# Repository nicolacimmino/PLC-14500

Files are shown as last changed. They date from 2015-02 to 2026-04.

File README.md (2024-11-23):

**NEW!** You can now buy this as a ready to assemble kit on [tindie.com](https://www.tindie.com/products/28867/).

# Introduction

The PLC14500 Nano is a retro-style trainer board intended for the user to familiarize with the Motorola MC14500 1-bit
ICU (Industrial Control Unit), PLCs and Ladder Logic. The board has abundant LEDs that show the status of 
the system buses and registers. This, combined with the possibility to run the software step by step,
gives the user a great deal of insight into how their programs are executing. The slow clock mode 
makes instead for a mesmerizing light show that won't fail to impress when the board is parked on a desk,
waiting for the next coding adventure.

Main features:

* 256 Bytes of program RAM (can be replaced with an EEPROM)
* 7 Inputs each with toggle and momentary switch capability
* 7 Outputs (LEDs)
* 1 Timer mapped to the I/O bus (0.5 to 11s, adjustable via a trimmer)
* 7 bits scratchpad RAM
* 3 clock modes (fast, slow, manual step)

True to its retro style PLC14500 Nano sports exclusively through-hole components and chips in DIP packages.
You might notice an intruder in the Bill of Materials, an Arduino Nano! It's there purely to act as a
bootloader, with a convenient USB interface that surely is easy to connect to modern PCs. However,
to not spoil the illusion, the Arduino is mounted on the bottom side of the PCB, so it won't be visible when 
using the board.

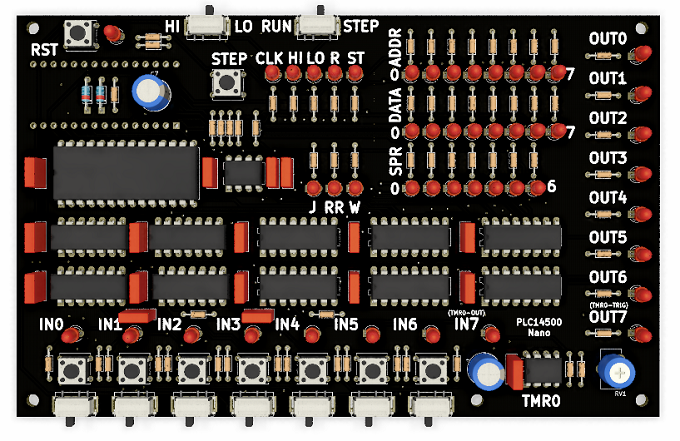
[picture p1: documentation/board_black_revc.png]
Board


This project is Open Source Hardware [Certified](https://certification.oshwa.org/pl000011.html)

oshw_PL000011

# Toolchain

You can find all the tools to assemble and transfer programs ready built for Windows in the [releases](https://github.com/nicolacimmino/PLC-14500/releases) section.

In addition to the tools in this repo, Hein Pragt was so kind to build a workbench that you can use to simulate your programs while waiting to build the board. See an in-depth explanation of the MC14500 and of the tool on his [website](https://www.heinpragt.nl/?p=2749).

# Assembling the board

To keep the assembled board visually free from clutter, and to give more prominence to the labels
relevant in regular use, it was chosen to hide the component reference numbers on the silkscreen.
Where possible these are on the silkscreen under the component itself but, where not possible, 
these have been omitted completely. To help with the assembly please refer to the assembly view 
available in the `board` folder.

**NOTE** Make sure you refer to the right revision of the board matching the one you have. The board
revision can be found on the bottom side silk screen (eg `PLC14500 Nano REV.A`)

As usual start from the lower profile components (such as resistors and ICs), and work towards taller
profile ones, to finish with large caps and the trimmer. 

**NOTE** The Arduino Nano is to be assembled on the bottom side of the board, opposite the components,
as indicated in the silk screen. Also, make sure D40, D51, R54, C7 are soldered BEFORE you solder the 
Arduino as their PINs are under the Arduino board.

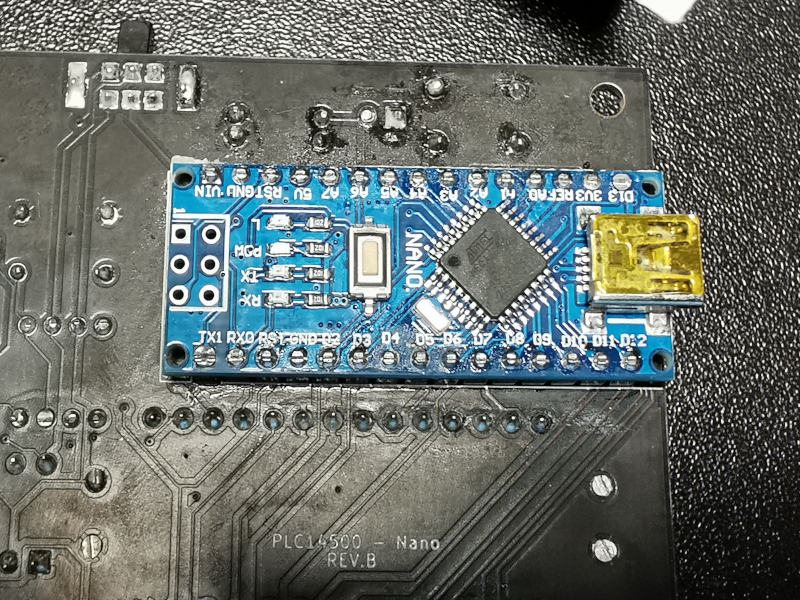
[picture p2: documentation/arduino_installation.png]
Arduino Installation


# Getting started

Download the latest toolchain (Windows only at the moment) from this Git repo [releases folder](https://github.com/nicolacimmino/PLC-14500/releases) and unzip it.

Before starting writing your programs and testing them on the board, you will need to flash the bootloader
into the Arduino. This can be easily done with the Arduino IDE. Load the sketch `bootloader.ino` from  the
release zip and make sure the board selected in the Arduino IDE is "Arduino Nano". Connect the board to your PC 
with a USB cable and select, in the Arduino IDE, the new serial port that will be assigned to the board. 
Upload the sketch and you are ready to go. Take note of the serial port name as you will need it to flash the
programs later.

Unless there will be an update to the bootloader you won't need to repeat this step in the future.

# Assembling a program

You can write your programs in a text editor of your choice, as long as you save them with a `.asm`
extension. This is a first example program to make sure your board is correctly assembled and functioning.
You can find this code also in the release zip file under `examples\smoketest.asm`.

````
.board=PLC14500-Nano

; *************************************************
; Prepare:
; All inputs off except IN6 (master switch).
; *************************************************

IEN IN6   ; IN6 acts as master switch
OEN IN6   ; to enable/disable all I/O

; *************************************************
; Test: Input and outputs are working correctly

LD  IN0   ; Load IN0,
AND IN1   ; logical AND it with IN1
STO OUT0  ; and show the result in OUT0.

; Expect: OUT0 is on only when both IN0 and IN1 are on.
; *************************************************

; *************************************************
; Test: TMR0 is working correctly

LD  IN2   ; Load IN2
STO OUT7  ; use it to trigger TMR0.

; Expect: Clicking IN2 on turns on IN7 (TMR0 output)
;   and, after few seconds, IN7 returns off.
; *************************************************

; *************************************************
; Test: Scratchpad RAM is working correctly.

LD  IN3    ; Copy IN3 to SPR0
STO SPR0

LD  SPR0   ; Copy SPR0 to SPR1
STO SPR1

; Expect: Clicking IN3 turns on SPR0 and SPR1
; *************************************************

JMP 0     ; Repeat.
````

Save it to a `test.asm` file and assemble it into a binary with the assembler found in the release zip file:

````
.\asm14500.exe .\test.asm
````

This will produce a `test.bin` file, which should be 256 bytes in size.

# Transferring a program to the board

To transfer the assembled `.bin` file to the board program RAM, make sure the USB cable is plugged in and take note of which serial port 
your board got mapped to in the Arduino IDE. You can then upload the flash command found in the release zip file:

````
.\flash14500 test.bin COM3
````

Replacing `COM3` with the correct port number for your board. Also remember to press the RST button on the board once the upload is done, and verify
that the top switches are in the "HI" and "RUN" positions respectively so the program runs.

# Testing

If you uploaded the above example program you can verify the board correct functioning by following the steps in the sourcecode that will guide you
through the needed settings and actions and expected outcomes.

**Help!!** some LEDs like `J`, `RR` or `W` randomly change intensity when I click other buttons. Do I have have a short somewhere? Did I break something? **no**,
don't worry. This is absolutely normal when the board is running on the normal clock (`HI` and `RUN`), this is because those LEDs are actually flashing on and off
as the MC14500 executes instructions. Because of the high clock speed you don't see the actual flickering but the resulting intensity depends on how often your program
causes them to be on (and for this reason, depending on the program, this is dependent on status of the inputs). This is also true for the `ADDR`, `DATA` and `SPR` LEDs when running with full clock. To convience yourself about this, and for a cool blinking effect, turn the clock to `LO` and watch, just don't expect outputs to react to your clicks promptly!

# What's next

Read more about the assembler and the `.asm` file syntax in the assembler folder [README.md](assembler/README.md).

To get started with programming your board and for some ideas of new programs you can try to make yourself, read the [Programmers Guide](assembler/programmers_guide.md).

If you find any issues, or want to contribute code/comments please feel free to use the "Issues" tool here on GitHub.

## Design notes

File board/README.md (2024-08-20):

## REV_A -> REV_B

- Moved LED labelled HI to the left of LO (to match switch direction)

- Added 47K in series to U2 Pin3 OUT (to remove gosthing of outputs on inputs LEDs due to MC14500 W line timing)

- Passed OUT7 through a NOT before triggering TMR0, left LED direct to OUT7 (NE555 triggers on low which makes it hakward without negation as the monostable triggers always once on reset)

- Swapped RV1 Pin3 and Pin1 (so clockwise rotation increases time)

*NOTE* REV.A was never on sale, it was a pre-production proto. If you have got a REV.A you either got a
knockoff by someone who got the gerbers in the early days or somehow you got hold of a display unit
from a museum.

## REV_B -> REV_C

- Replaced SPR7 with RR so that RR can be read at IO $7
- Replaced C4 with a 10uF and RV1 with 1M. Similar timing but more consistent when triggered by short pulses.

  (Thanks to [wrh3c](https://github.com/wrh3c) for the suggestion).

If you have a REV.B and you are interested in experimenting with the ION/OEN driven if/else structures
described in the Motorola's own MC14500 Handbook, you will need a tiny modification to the board. This
will replace SPR7 input signal with RR so that you can control IEN/OEN registers fully.

- Cut pin 1 of U13 (isolates the Q7 output of the CD4099, leaving what used to be SPR7 floating )
- Connect the **pad** of pin 1 of U13 to pin 15 of U10 (thus connecting the MC14500 RR to what used to be SPR7 input)
- If having the SPR7 LED confuses you, cut LED D50

## REV_C -> REV_D

- Corrected clock source to feed into X2 and used X1 to drive the counter. There are no functional changes.

- Added LEDs also for RTN, FLAG0, FLAGF. Even though these signals are not relevant for this design
	many asked to have them visible for educational purpuses.

- Rearranged ADDR, DATA, SPR LEDs to have lsb on the right.

- Rearranged OUT LEDs in a more compact layout like the others.

- Added an expansion connector to use external inputs/outputs.

- Swapped around the wiring of input switches so that right is ON left is OFF.

- Swapped around the wiring of the clock switches so that HI and RUN are on the right.

## REV_D Artifacts

Silk
Silk

Assembly
Assembly

TopCopper
Top

BottomCopper
Bottom

## REV_C Artifacts

Silk
Silk

Assembly
Assembly

TopCopper
Top

BottomCopper
Bottom

## REV_B Artifacts

Silk
Silk

Assembly
Assembly

TopCopper
Top

BottomCopper
Bottom

## REV_A Artifacts

Silk
Silk

Assembly
Assembly

TopCopper
Top

BottomCopper
Bottom

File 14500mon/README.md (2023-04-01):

# 14500MON (PLC14500 Assembler and Monitor)

Your PLC14500 comes preloaded with the 14500MON. This interactive assembler/monitor is an homage, both in the name and
in the syntax, to the classic C64 monitor 64Mon and other similar implementations.

**Note:** while 14500MON is compatible with ALL revisions of the board, early REV.B and a batch of REV.C boards were shipped
without it (the regular bootloader only was provided). You can just use an Arduino IDE to load the sketch on your PLC14500 (Choose Arduino Nano under AVR Boards
and make sure you choose the "Old Bootloader" variant).

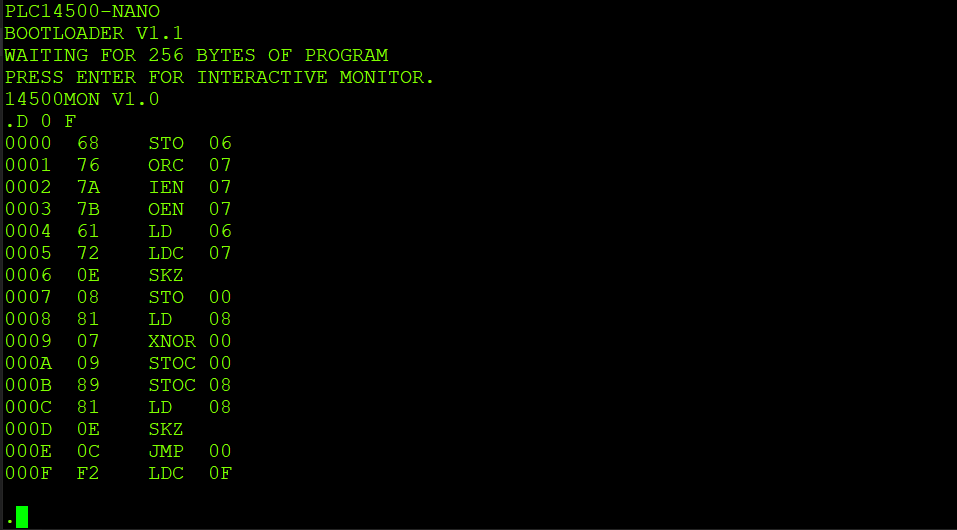
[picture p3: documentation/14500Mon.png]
14500mon


To verify if you have the 14500MON already installed, open a terminal program (e.g. PuTTY) and connect to the PLC14500
serial port (9600 BAUD, no parity, 8bits, 1 stop bit). After a few seconds you should receive the prompt:

````
PLC14500-NANO
BOOTLOADER V1.1
WAITING FOR 256BYTES OF PROGRAM
PRESS ENTER FOR INTERACTIVE MONITOR.
````

Press enter and you will be in the monitor. The monitor will exit automatically after 30s of inactivity, or you can exit
by giving the “X” command.

**Note:** while the monitor is active, even if you disconnect the serial port, the bootloader won’t be running and you
will
not be able to flash new programs until it exits.

**Warning:** Depending on the settings used on your terminal app, the first usage of “flash14500.cmd” after exiting the
monitor might not transfer the program correctly. This is because “flash14500.cmd” might end up toggling the serial port
control lines causing the Arduino to reset. This introduces a delay that will make it miss the payload. Any further
flashing after the first will work as expected.

# Commands

The following commands are available in 14500MON and can be listed at any moment by using the “H” command. Just type “H”
at the prompt and press enter.

````
.H
A [START]       ASSEMBLE
D [START] [END] DISASSEMBLE
L [BLOCK]       LOAD
M [START] [END] DUMP MEMORY
S [BLOCK]       SAVE
T TRACE
W [START]       WRITE MEMORY
X EXIT
````

## Assemble

The built-in assembler is a great way to try small programs and see them immediately running on the board. It also gives
you a more down to the machine view of how assembly language is converted to bytecode.

To assemble interactively simply use the “A” command followed by the start address and press enter:

````
.A 0
````

The assembler will reply with something like:

````
.A 0
0000 68 STO 06 .
````

The first four digits are the address and the following number is the memory content at that location. This is followed
by a disassembly of the instruction at that address and the “.” prompt. We can now type a new instruction to be
assembled at this location, for instance “LD 6” and press enter. The instruction will be assembled, written to memory,
and the assembler will move to the next location.

````
.A 0
0000 68 STO 06 .LD 6
0001 76 ORC 07 .
````

We can continue in this way to assemble our program. If we leave a line empty and just press enter the assembler will
move to the next memory location and leave the current one untouched. This is useful for instance to revise the current
program and fix only some instructions if a bug is found.

````
.A 0
0000 68 STO 06 .LD 6
0001 76 ORC 07 .LD 7
0002 7A IEN 07 .
````

Once we are done we can exit the assembler with the “X” command.

````
.A 0
0000 68 STO 06 .LD 6
0001 76 ORC 07 .LD 7
0002 7A IEN 07 .
0003 7B OEN 07 .X
````

**Note:** while you are in the "assemble" command, the board stops executing code. Normal execution will resume once you
exit the assembler. This prevents inconsistencies that could be caused by non-complete code being executed.

**Note:** the program you are assembling is stored in the PLC14500-Nano onboard RAM but is not persisted in the
bootloader storage. If you power cycle the board, the old program will be re-loaded. To persist your changes for the
next boot see the “SAVE” command.

Remember to always press “RST” after modifying the code to ensure your I/O latches start from a clean state.

## Load

The “LOAD” command, invoked with “L”, will cause a program currently in the bootloader EEPROM to be loaded into the
PLC14500-Nano onboard RAM for immediate execution.

The bootloader has four separate blocks of storage that can store one program each. Block 0 is the one loaded by the
bootloader when the board is powered up. The programs in the other three blocks can be loaded only with the “LOAD”
command.

The “L” command takes one argument, that is the block number to be loaded. Block numbers above 3 will cause an error.

````
.L 1
LOADING................
````

**Note:** Remember to always press “RST” after modifying the code to ensure your I/O latches start from a clean state.

## Save

The “SAVE” command, invoked with “S”, will cause the program currently in the PLC14500-Nano onboard RAM to be persisted
in a bootloader EEPROM block for later retrieval.

The bootloader has four separate blocks of storage that can store one program each. Block 0 is the one loaded by the
bootloader when the board is powered up. The programs in the other three blocks can be loaded only with the “LOAD”
command.

The “S” command takes one argument, that is the block number to be loaded. Block numbers above 3 will cause an error.

````
.S 1
SAVING................
````

**Note:** only block 0 can be written from the USB through the bootloader. The other three blocks are meant to be used
by the interactive monitor with the “SAVE” and “LOAD” commands. You can save on block 0, this program will be
automatically loaded next time you boot the board. However, keep in mind if you transfer a program from the USB port
this block will be overridden.

## Disassemble

The disassemble command can be invoked with “D” followed by a start and end address (in hexadecimal). The start address
is optional and, if omitted, 0 will be assumed. The end address is also optional and, if omitted, the program will be
disassembled till the end of program memory.

````
.D 0 5
0000 68 STO 06
0001 76 ORC 07
0002 7A IEN 07
0003 7B OEN 07
0004 61 LD 06
0005 72 LDC 07
````

Each line of the disassembly shows the address, the numeric content of the memory location, and the mnemonic and operand
this translates to. Because the MC14500 has 16 instructions and 4-bit wide instruction bus there are no illegal opcodes,
so any memory content will always produce a valid disassembly.

## Dump Memory

The dump memory command can be invoked with “M” followed by the start and end address (in hexadecimal). The start
address is optional and, if omitted, 0 will be assumed. The end address is also optional and, if omitted, the memory
will be dumped till the end of program memory.

````
.M 0 1F
0000 68.76.7A.7B.61.72.0E.08
0008 81.07.09.89.81.0E.0C.F2
0010 7B.F8.F9.51.68.41.58.31
0018 48.21.38.11.28.01.18.61
````

Each line shows the address of the first byte, followed by the values of the memory content for the following eight
memory locations.

**Note:** if the selected start doesn’t align to an eight byte boundary, values will still be printed in blocks aligned
to the boundary, just with the unwanted values missing. This can be seen in the example below:

````
.M 3 1B
0000 7B.61.72.0E.08
0008 81.07.09.89.81.0E.0C.F2
0010 7B.F8.F9.51.68.41.58.31
0018 48.21.38.11.
````

## Write Memory

The "write memory" command can be invoked with “W” followed by the start address. The start address is optional and, if
omitted, 0 will be assumed. The monitor will show the first address, followed by the current content of that memory
location . A new value can be entered and will be stored in memory when enter is pressed. It’s possible to leave the
line empty and just press enter to skip that memory location without changing its contents.

````
.W A3
00A3 0F .12
00A4 0F .F0
00A5 0F .
00A6 0F .
00A7 0F .X
.
````

**Note:** the program you are entering in this way is stored in the PLC14500-Nano onboard RAM but is not persisted in
the bootloader storage. If you power cycle the board, the old program will be re-loaded. To persist your changes for the
next boot see the “SAVE” command.

Remember to always press “RST” after editing the program to ensure your I/O latches start from a clean state.

## Trace Program Execution

Thanks to [wrh3c](https://github.com/wrh3c) from whom I got the inspiration to add the Trace mode.

The “Trace Program” mode can be entered using the “T” command. In this mode the monitor will keep outputting the current
instruction being executed.

````
.T
ADDR DATA OP ARG
001B 18 STO 01
001C 61 LD 06
001D 08 STO 00
001E 01 LD 00
001F 88 STO 08
.
````

The output shows the current memory address at which the Program Counter is at, the data in memory at that location and
a disassembly of the instruction. The trace mode will continue until you press a key.

This command is extremely useful when combined with the single step clock as it allows to see the exact instruction
being executed in a more direct way than analysing the LEDs on the board.

**Note:** due to the nature of the PLC14500-Nano bus control, the monitor is not able to keep up with the program being
run at full clock speed (and neither would your eyes). If the trace mode is running with the clock running at full speed
the following error will be displayed:

````
.T
ADDR DATA OP ARG
0004 61 LD 06
0006 0E SKZ
TOO FAST, CAN’T KEEP UP. TURN CLOCK TO LO OR STEP.
````

Changing the clock to LO or STEP will resume the trace at the next clock cycle.

**Note:** there’s no timeout for the trace command. If you leave your board in trace mode the bootloader will not be
able to
receive new programs. If this happens, reconnect to the serial port, press any key and exit the monitor with “X”.
Alternatively you can just unplug and replug the USB cable or reset the Arduino (the RST button on the board itself will
NOT affect the bootloader, just the board PC and I/O latches).

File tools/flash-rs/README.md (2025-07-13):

# flash-rs (PLC14500 Program Flasher and Interactive Monitor Terminal Emulator)
flash-rs will upload a program to the PLC14500 and then provide access to the interactive monitor.

## Use
First install a Rust compiler.  You can find one [here](https://www.rust-lang.org/tools/install).  Then, build the flash-rs for your machine by running the following command anywhere within the flash-rs project  
`cargo build`  

An executable will now be present in the target directory, and you can run the executable directly or use  
`cargo run`

## Syntax
`./flash-rs <program filepath> <serial port interface>`  
Example:  
`./flash-rs example.bin /dev/ttyUSB0`

There's a number of different ways to produce a program.  See the [Getting Started of this repository](https://github.com/nicolacimmino/PLC-14500/blob/master/README.md) as well as the [Assembler Repository](https://github.com/nicolacimmino/plc-14500-assembler).

## Known issues
* When using the trace feature, you cannot exit the trace by pressing X.  You can get out by setting the speed switch to HI to cause an error or by pressing the reset switch on the Arduino.

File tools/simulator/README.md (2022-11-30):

# Simulator

Simulator for PLC14500-Nano board.

This is Work Heavily in Progress. 

A flutter application to toy around with the board while you wait to receive the kit. The app roughly works and basic programs seem to run. Nothing is tested properly though and layout is still a mess.

This will not be part of the first release. However, I plan to polish it later and make a static website out of it for people to play around.

simulator

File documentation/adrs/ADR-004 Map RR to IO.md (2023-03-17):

Status: #Accepted

## Context

The original design of the board doesn't map the MC14500 RR output to the I/O bus. This means that
the OEN instruction cannot be used to its full power to create conditional IF/ELSE blocks.

## Decisions

Reduce SPR size to 7 bits and use SPR7 as an input wired directly to the MC14500 RR pin.

## Consequences

Board needs to be adapted and bumped to REV.C
Assembler needs to be updated to define a RR label.
SPR7 won't be anymore usable for write and reading it will always return RR.

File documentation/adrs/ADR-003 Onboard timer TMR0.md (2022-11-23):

Status: #Accepted

## Context

Given the nature of the board (a trainer board), the onboard TMR0 range can be limited, hence simplifying the design.

## Decisions

It's been decided to have a range for TMR0 from 1s to 6s, while this would be way too short for most practical applications, it suites very well the purpose in the context of test apps for which it's not desirable to have long times to wait for an event to happen. The 1s time constant also allows for blinking of an output if desired.

## Consequences

TMR0 can be implemented with a single 555. A 10K trimmer, with a fixed 2K2 resistor will give the desired range with a 470uF cap.

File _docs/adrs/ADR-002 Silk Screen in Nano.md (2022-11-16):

Status: #Accepted

## Context

Given the limited board space and the amount of components the silk screen for the top layer is rather cluettered. This doesnt sit well with the nature of the board which is in itself a display. The user needs to clearly identify the LEDs functions (eg address bus, inputs, outputs, SPR etc.).

## Decisions

It's been decided to keep the silk screen content unclattered and give prominence to the text relevant to the user during normal usage (as opposed to the assembly phase). This can be achieved by moving all components references under the component itself where possible, so it won't be visible after assembly. Where not possible to fit it under the component it will be hidden completely.

## Consequences

To aid the user in the kit assembly a layout of the components will need to be provided in printed form. This is available from KiCad as the `F.Fab` layer.

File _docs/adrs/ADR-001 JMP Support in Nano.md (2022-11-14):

Status: #Accepted

## Context

Given the lack of an interanal Program Counter (PC) in the MC14500 eventual support for JMP instructions needs to be provided externally. This means a different PC with a preset facility and, short of a cumbersome paging system, a larger Program Memory data path (4 bits are for the instruction, so only 4 are left for the operand).

## Decisions

To keep be BOM low and simplify the board programmers model for the Nano version, it's been decided to not provide JMP capability. The JMP flag though has been connected to the PC reset de -facto hardcoding the JMP instruction to `JMP 0`. The rational behind this is that, while the program space is not too large (256 bytes) and it could be filled with `NOPO`/`NOPF`  (so the program loops around) there are two drawbacks of not supporting `JMP 0`:

- Cumbersome when stepping the program
- Would allow only programs that run a single loop

## Consequences

The chosen approach allows to implement conditionals mixing the `SKZ` and `JMP 0` , which is desirable to have multiple code exectution paths.

The assembler will need to have code preventing assembling any other address than `0` for the `JMP` to avoid confusion for the user. This should be conditional for the Nano.

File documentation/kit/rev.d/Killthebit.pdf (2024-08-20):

;
; Kill the bit for PLC14500-Nano.
;
; NOTE! This game requires a REV.C/D (or a modified REV.B). The game is playable
; | on the standard clock (R30=1K, 4.8KHz) as opposed to the version for REV.B
; | that required the clock to be dropped to make the game playable.
; | This is one example of the power of the IEN/OEN instructions that allow us
; | to execute conditionally the bit shift block only every 4 rounds of the
; | program, thus introducing the delay.
;
; The game idea itself is from a game for the Altair by Dean McDaniel in 1975. ; Original Description:
; | Object: Kill the rotating bit. If you miss the lit bit, another
; | bit turns on leaving two bits to destroy. Quickly
; | toggle the switch, don't leave the switch in the up
; | position. Before starting, make sure all the switches
; | are in the down position.
;
; The idea to implement it on the MC14500 came to me after watching this awesome
; | build by Usagi Electric: https://www.youtube.com/watch?v=md_cPxVDqeM
; | Also the code was heavily adapted from this one:
; | https://github.com/veremenko-y/mc14500-programs/blob/main/sbc1/killthebit.s
;

.board=PLC14500-Nano

.io_GAME_BIT0=SPR0 ; Game bit 0 .io_GAME_BIT1=SPR1 ; Game bit 1
.io_GAME_BIT2=SPR2 ; Game bit 2
.io_GAME_BIT3=SPR3 ; Game bit 3
.io_GAME_DLY0=SPR4 ; Game delay bits used as a 2-bit counter
.io_GAME_DLY1=SPR5 ; | to shift the bit only once every 4 rounds.
.io_SWAP=SPR6 | ; Swap bit used for temporary storage
.io_GAME_LED0=OUT0 ; Game LED 0
.io_GAME_LED1=OUT1 ; Game LED 1
.io_GAME_LED2=OUT2 ; Game LED 2
.io_GAME_LED3=OUT3 ; Game LED 3 .io_GAME_LED4=OUT4 ; Game LED 4 .io_GAME_BUTTON=IN0 ; Game only button
STO | SWAP | ; Save RR
ORC | RR | ; RR=RR|!RR (always 1)
IEN | RR | ; Enable inputs
OEN | RR | ; Enable outputs
LD | SWAP | ; Restore RR

; This STO is executed only once because after the first loop we
; | set RR=1 (see last line of the whole program), so when we come here
; | RR is 1 and LDC will load a 0.
LDC | RR | ; This is 1 on reset (RR is initialised to 0)
SKZ
STO | GAME_BIT0 | ; initialise memory with 1 initial bit

; Kill (or set!) the first bit.
; The bit will be killed if the button is pressed while it's high.
LD | GAME_BUTTON
XNOR | GAME_BIT0
STOC | GAME_BIT0

; Rotate all bits forward (and last back to first).
; | But only every 4 rounds to slow down the action.
LD | GAME_DLY0 | ; Negate GAME_DLY0
STOC | GAME_DLY0
OEN | RR | ; If GAME_DLY0 transitioned to 0
LD | GAME_DLY1 | ; negate GAME_DLY1
STOC | GAME_DLY1
AND | GAME_DLY0
OEN | RR | ; endif if GAME_DLY1 and GAME_DLY0 are 1
LD | GAME_BIT3
STO | SWAP
LD | GAME_BIT2
STO | GAME_BIT3
LD | GAME_BIT1
STO | GAME_BIT2
LD | GAME_BIT0
STO | GAME_BIT1
LD | SWAP
STO | GAME_BIT0
ORC | RR | ; RR=RR|!RR (always 1)
OEN | RR | ; endif always

; Display the game status by showing on the outputs the values stored in SPR. ; Note: we don't play directly on SPR as that would be confusing as some bits
; | in SPR are used to store temporary values.
LD | GAME_BIT0
STO | GAME_LED0
LD | GAME_BIT1
STO | GAME_LED1
LD | GAME_BIT2
STO | GAME_LED2
LD | GAME_BIT3
STO | GAME_LED3
ORC | RR | ; RR=RR|!RR (always 1)
| | ; This will cause the code that initialises the game bit
; | to be skipped.

; Don't JMP 0 here, the rest of the code will be
; | filled with NOPF and act as a delay, otherwise the
; | game will be too fast.

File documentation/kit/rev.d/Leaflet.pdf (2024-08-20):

Thanks for purchasing a PLC14500 - Nano. Whether you got the
full | kit, | or | just | the | board | and | will | be | sourcing | the
components yourself, what awaits you is a retro-style trainer board based on the Motorola MC14500 1-bit ICU. The board has abundant LEDs that show the status of the system buses and registers. This, combined with the possibility to run the software step by step, will give you a great deal of insight into how your programs are executing. The slow clock mode will make for a mesmerising light show. It won't fail to impress your guests when the board is parked on a desk, waiting for your next coding adventure.

In this guide you will find all the information you need to assemble and test the board as well as to move your first steps to program it.

This | project | is | Open | Source | Hardware | Certified | because | I
believe people can learn a lot not only by using the finished product, but by being able to see how it was designed and how the software that supports it works.
If | you | feel | you | have | something | to | contribute, | need
clarifications or would like to get in touch for any other reason, feel free to do so on the “Discussions” section of the project’s GitHub page (github.com/nicolacimmino/PLC-14500).

___________________

Nicola Cimmino

# Assembling the board

To keep the assembled board visually free from clutter, and to give more prominence to the labels relevant in regular use, it was chosen to hide the component reference numbers on the silkscreen. Where possible these are on the silkscreen under the component itself but, where not possible, these have been omitted completely. For this reason you won’t be able to see all the component values on the silkscreen. Please refer to the assembly plan included.

NOTE: Double check that the the revision label on the assembly plan matches the one at the back of the board (eg. “REV.D”). If you received for any reason an assembly plan for the wrong board revision, you can find the right one on the GitHub repo under “/board”).

Before starting the assembly double check you received all components as per bills-of-materials included in the kit.

You will need a soldering iron with a medium/fine tip and

solder (anything not too thin will do). All components are through-hole so you won’t need very specialised tools. You could use a multimeter to help you recognize the resistors if you are not familiar with the colour coding.

It will be useful to have some IPA (Isopropyl Alcohol) to clean the board soldering work at the end.

Start soldering from the lowest profile components such as resistors and diodes. Pay attention to the orientation of the 1N4148 diodes, the cathode is marked by a band on the body of
the | component, | which | needs | to | match | the | band | on | the
silkscreen. Resistors are unpolarized, so they can be inserted either way.

Move on then to the push-buttons. Due to slight tolerances and the springiness of the pins you might need to slightly spread the pins for them to fit snugly in the holes. After the buttons it’s a good idea to do the slider switches. To ensure they are flush with the board, solder only one pin of each first. Then rework them one by one by pressing with a finger on the top of the body of the switch and re-heating the solder point until the switch sits flat on the board. You can then proceed to solder all the other pins. NOTE: to prevent thermal damage to the switches it’s a good idea to solder one pin at the time of each switch, then move on to the next switch and so on. This will leave time for them to cool down.

Next are the ICs. Pay close attention to the markings on the body, helping yourself with a magnifying glass where needed. Many chips have the same amount of pins but are different! Also pay attention to the orientation of the chip. The side with pin 1 has a half-circle indent that needs to be aligned with the side with pin 1 on the silk screen (the cut-off
corner). | If | you | look | at | the | board | with | the | silk | screen
oriented for normal reading, all chips’ pin 1s are on the left. As for the switches, solder only one pin of each IC, rework it while pressing on the body to ensure it sits flat,
and | then | solder | the | remaining | pins | alternating | between
different chips to avoid overheating.

Proceed with the LEDs. All cathodes are towards the left side of the board, the cathode is the shortest of the two leads. To ensure the LEDs sit flush and are nicely aligned, solder a single pin of each first and then rework them one by one while holding the board in your hand and pressing with a finger on the LED.

Next are the 100nF polyester capacitors. These are unpolarized so the direction doesn’t matter. Move on then to the 470uF electrolytic capacitors. These are polarised so you need to pay attention to the orientation. The negative terminal is marked by a grey band, with a “-” sign on the body. The opposite terminal is the “+” and you will find that marked on the board.

Last on this side of the board is the variable resistor. This can fit in only one position so it should be easy to orient.

You can now move to the back of the board where the only component is the Arduino Nano that provides the USB interface for the board and its bootloader. Assemble the pin headers on the Arduino board first, then sit the board with the headers into the matching pin holes and solder from the components side.

# Testing the Board

If you purchased the full kit the Arduino comes pre-loaded
with | the | bootloader | and | flashed | with | the | smoke-test
application. | If | you | opted | for | sourcing | the | components
yourself, please refer to the “Getting Started” section on the
GitHub | README.md | in | the | root | folder | of | the | repository
(https://github.com/nicolacimmino/PLC-14500/README.md) | for

instructions on how to load the bootloader into the Arduino and compile and flash your PLC14500 programs.

The smoke test program pre-flashed is designed to provide a
simple | way | to | verify the main features of the board and
validate the assembly. The source code is reported in the next
page | and | contains, | in | the | comments, | the | steps | needed | to
perform each step of the test.

.board=PLC14500-Nano
; ************************************************* ; Prepare:
; All inputs off except IN6 (master switch).

; *************************************************

IEN IN6 | ; IN6 acts as master switch
OEN IN6 | ; to enable/disable all I/O

; ************************************************* ; Test: Input and outputs are working correctly

LD | IN0 | ; Load IN0,
AND IN1 | ; logical AND it with IN1
STO OUT0 | ; and show the result in OUT0.

; Expect: OUT0 is on only when both IN0 and IN1 are on.

; *************************************************

; ************************************************* ; Test: TMR0 is working correctly

LD | IN2 | ; Load IN2
STO OUT7 | ; use it to trigger TMR0.

; Expect: Clicking IN2 on turns on IN7 (TMR0 output)

; and, after a few seconds, IN7 returns off.
; *************************************************

; ************************************************* ; Test: Scratchpad RAM is working correctly.

LD | IN3 | ; Copy IN3 to SPR0
STO SPR0
LD | SPR0 | ; Copy SPR0 to SPR1
STO SPR1

; Expect: Clicking IN3 turns on SPR0 and SPR1

; *************************************************

JMP 0 | ; Repeat.

# Next Steps

Now that your board is assembled and tested, go ahead to the
releases | folder | on | GitHub | to | download | the | latest | tools
(https://github.com/nicolacimmino/PLC-14500/releases).

You can then follow the instructions on the “Getting Started” section on the GitHub README.md in the root folder of the repository to learn how to write, assemble, and flash your own

programs.

The “Programmers Guide” is your next step as it provides more in depth information on the board programming model as well as practical examples to try and modify.

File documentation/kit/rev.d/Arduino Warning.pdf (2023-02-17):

# Warning!

Install the Arduino board on the bottom side (opposite the other components).

Install only AFTER installing D40, D51, R54, C7 or you won’t be able to solder them!


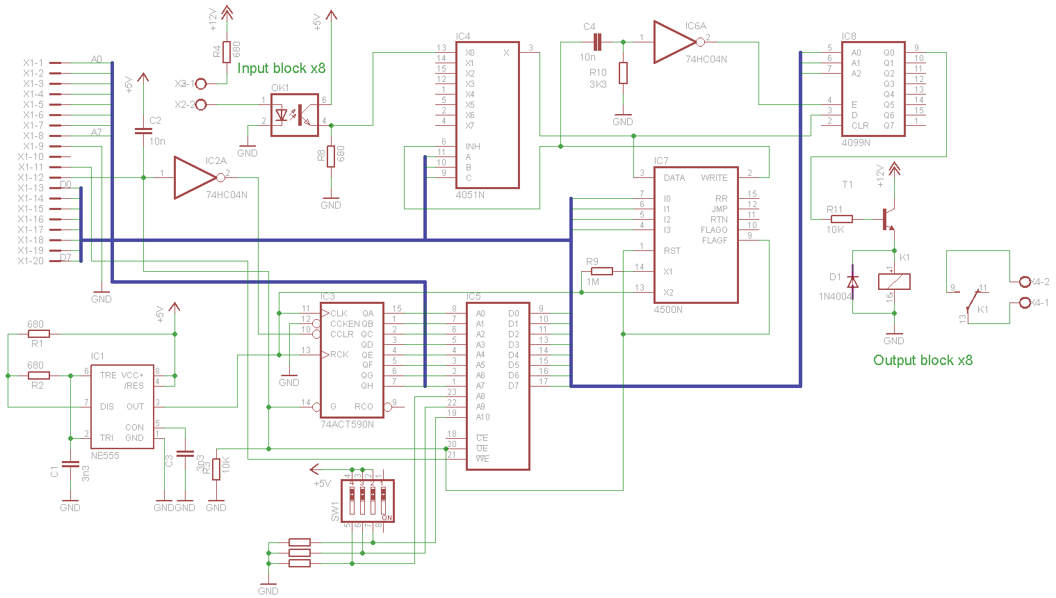
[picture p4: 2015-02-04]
_docs/schematic.png

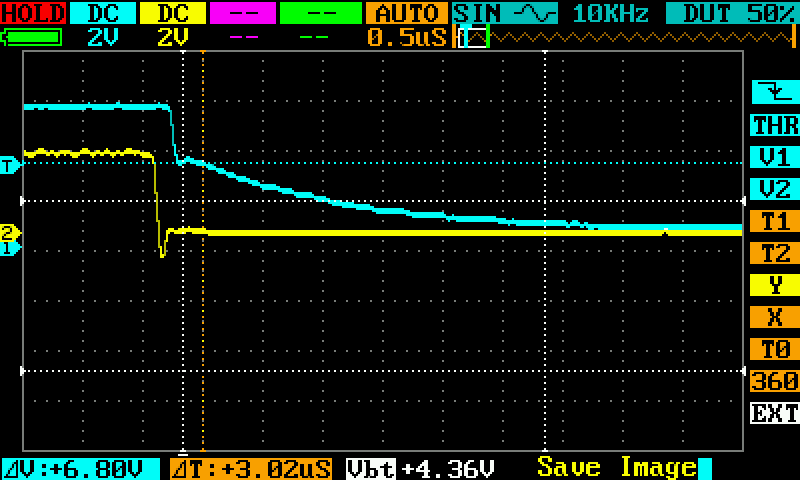
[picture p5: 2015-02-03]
_docs/capture1.png

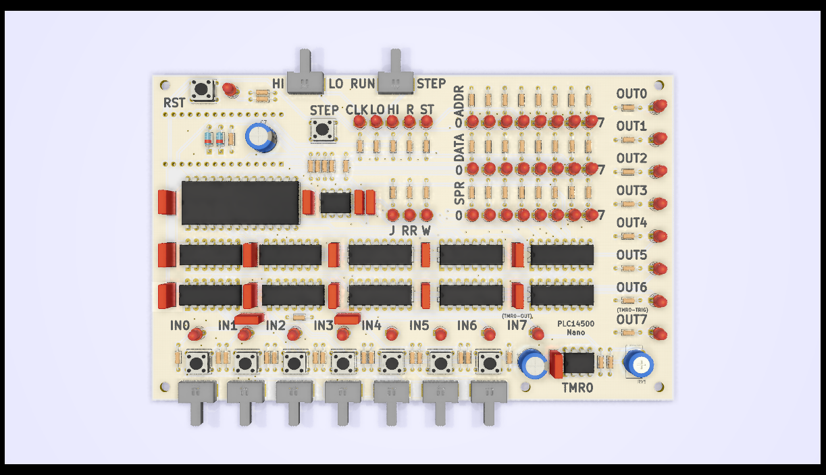
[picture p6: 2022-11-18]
_docs/board.png

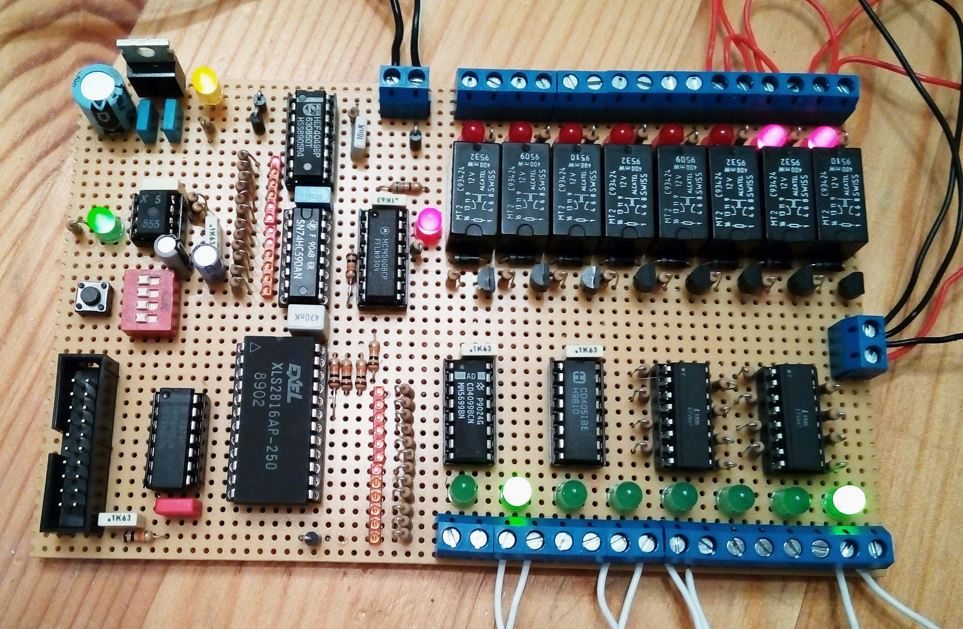
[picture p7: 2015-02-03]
_docs/board_full.jpg

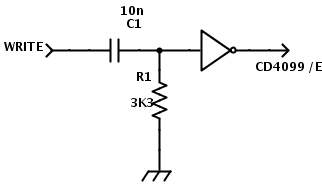
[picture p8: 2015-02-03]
_docs/monostable.png

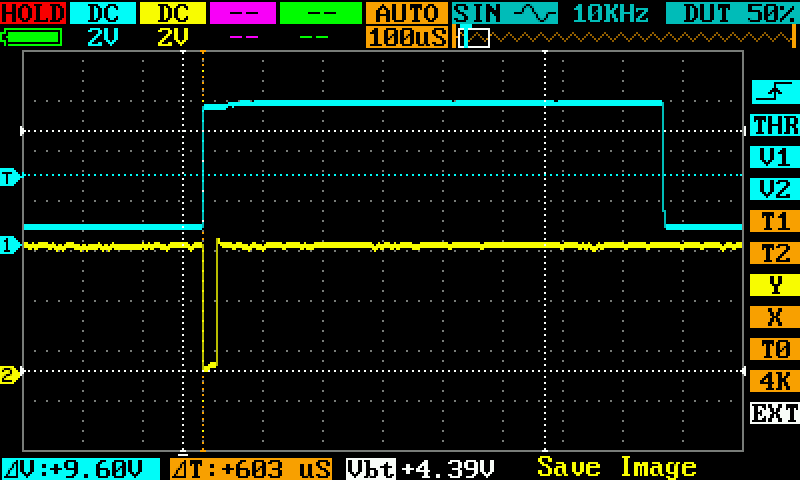
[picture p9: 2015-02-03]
_docs/capture2.png

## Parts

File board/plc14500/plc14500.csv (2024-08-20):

# | Reference | Qty | Value | Footprint | DNP
1 | C1, C2, C3, C5, C6, C8, C9, C10, C11, C12, C13, C14, C15, C16, C17, C18, C19 | 17 | 100nF | Capacitor_THT:C_Rect_L7.2mm_W2.5mm_P5.00mm_FKS2_FKP2_MKS2_MKP2
2 | C4 | 1 | 10uF | Capacitor_THT:CP_Radial_D5.0mm_P2.50mm
3 | C7 | 1 | 470uF | Capacitor_THT:CP_Radial_D5.0mm_P2.50mm
4 | C20 | 1 | 1uF NP | Capacitor_THT:C_Radial_D6.3mm_H5.0mm_P2.50mm
5 | D1, D2, D3, D4, D5, D6, D7, D8, D9, D10, D11, D12, D13, D14, D15, D16, D17, D20, D21, D22, D23, D24, D25, D26, D27, D29, D30, D31, D32, D34, D35, D36, D37, D43, D44, D45, D46, D47, D48, D49 | 40 | LED 3MM Red | plc14500:LED_3MM
6 | D18, D19, D28, D33, D38 | 5 | LED 3MM Yellow | plc14500:LED_3MM
7 | D39, D41, D42, D50, D52, D53 | 6 | LED 3MM Orange | plc14500:LED_3MM
8 | D40, D51 | 2 | 1N4148 | Diode_THT:D_DO-35_SOD27_P7.62mm_Horizontal
9 | J1 | 1 | ~ | plc14500:PLC14500-Expansion
10 | R1, R2, R3, R4, R9, R10, R11, R22, R26 | 9 | 47K | Resistor_THT:R_Axial_DIN0204_L3.6mm_D1.6mm_P7.62mm_Horizontal
11 | R5, R6, R7, R8, R12, R13, R14, R16, R17, R18, R19, R20, R21, R23, R24, R25, R27, R28, R29, R32, R33, R34, R35, R36, R37, R38, R39, R40, R41, R42, R43, R44, R45, R46, R47, R48, R49, R52, R53, R55, R56, R57, R58, R59, R60, R61, R62, R63, R64, R65, R66, R67 | 52 | 820R | Resistor_THT:R_Axial_DIN0204_L3.6mm_D1.6mm_P7.62mm_Horizontal
12 | R15 | 1 | 2K2 | Resistor_THT:R_Axial_DIN0204_L3.6mm_D1.6mm_P7.62mm_Horizontal
13 | R30, R31 | 2 | 1K | Resistor_THT:R_Axial_DIN0204_L3.6mm_D1.6mm_P7.62mm_Horizontal
14 | R50, R51, R54 | 3 | 10K | Resistor_THT:R_Axial_DIN0204_L3.6mm_D1.6mm_P7.62mm_Horizontal
15 | RV1 | 1 | 1M | plc14500:HORIZONTAL_POT
16 | S1, S2, S3, S4, S9, S10, S11, S15, S17 | 9 | Push Button | plc14500:SW_Tactile_THT
17 | S5, S6, S7, S8, S12, S13, S14, S16, S18 | 9 | Switch DPDT | plc14500:SWITCH_DPDT
18 | U1, U3, U11 | 3 | 74HC14 | Package_DIP:DIP-14_W7.62mm_LongPads
19 | U2, U14 | 2 | 4051 | Package_DIP:DIP-16_W7.62mm_LongPads
20 | U4, U9 | 2 | NE555 | Package_DIP:DIP-8_W7.62mm
21 | U5, U13 | 2 | 4099 | Package_DIP:DIP-16_W7.62mm_LongPads
22 | U6 | 1 | Arduino Nano | Module:Arduino_Nano
23 | U7 | 1 | 74HC590A | Package_DIP:DIP-16_W7.62mm_LongPads
24 | U8 | 1 | LH5168 | Package_DIP:DIP-28_W15.24mm
25 | U10 | 1 | MC14500 | Package_DIP:DIP-16_W7.62mm_LongPads
26 | U12 | 1 | 4011 | Package_DIP:DIP-14_W7.62mm_LongPads

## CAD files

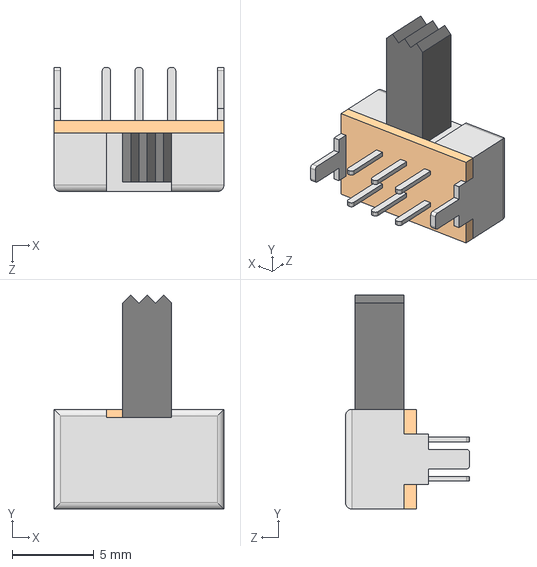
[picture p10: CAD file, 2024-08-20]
board/plc14500/SK2202.step
10.4 x 13.1 x 7.60 mm

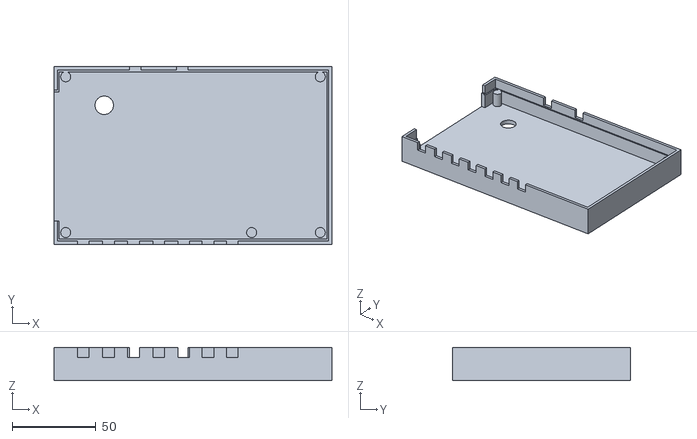
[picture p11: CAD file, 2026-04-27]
support/PLC14500-Nano-SupportV2-MainPlate.stl
166.0 x 106.0 x 20.0

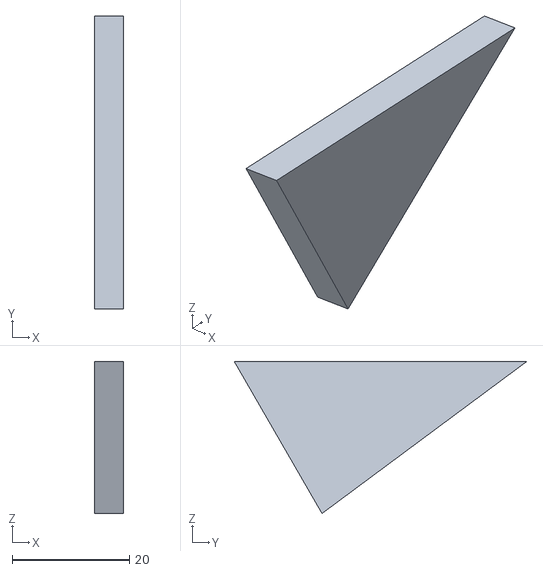
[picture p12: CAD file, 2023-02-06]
support/PLC14500-Nano-Support-MainPlateSupports.stl
5.00 x 50.0 x 26.0

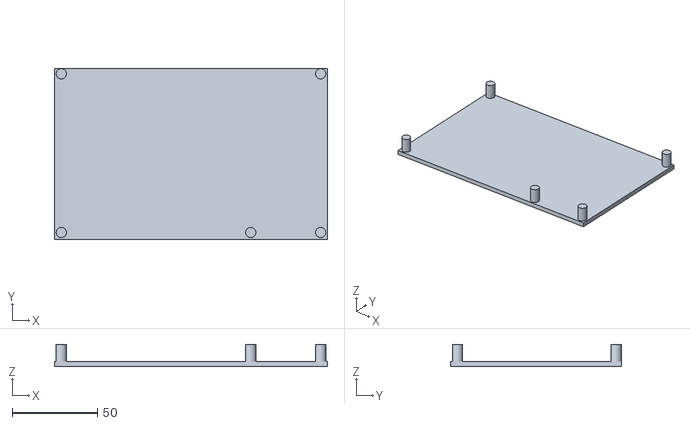
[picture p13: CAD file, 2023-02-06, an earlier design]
support/PLC14500-Nano-Support-MainPlate.stl
160.0 x 100.0 x 13.0

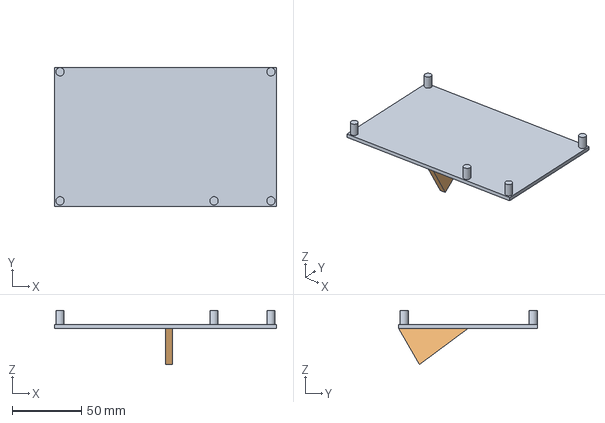
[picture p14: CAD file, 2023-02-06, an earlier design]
support/PLC14500-Nano-Support.FCStd
160.0 x 100.0 x 39.0 mm
MainPlate
MainPlateSupports

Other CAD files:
support/PLC14500-Nano-SupportV2.FCStd

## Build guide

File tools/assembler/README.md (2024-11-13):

# PLC14500 Assembler

You can find a precompiled version of the assembler and a batch file to flash the programs into the board in the
[releases](https://github.com/nicolacimmino/PLC-14500/releases) zip file. If you prefer to build your own, or you want
to build for something other than Windows, you will need to have a properly configured [Dart development environment](https://dart.dev/get-dart#install)
and build with:

````
dart compile exe "assembler\bin\assembler.dart" -o "asm14500.exe"
````

## Assembling

````
asm14500.exe test.asm
````

The output will be a `.bin` file of the same name. The output file is always 256 bytes for a PLC14500-Nano, your program
will be starting from offset 0x00 and will be padded to 256 with 0x0Fs (`NOPF`).

If you find the options of the assembler too crude I don't blame you. I recently came across this work by Yaroslav Veremenko
( https://github.com/veremenko-y/mc14500-programs ), that inspired me into using the cc65 assembler instead. Check the repo https://github.com/nicolacimmino/plc-14500-assembler for a build command and further information on how to use cc65 to compile programs for the PLC-14500.

## Source format

````
;
; Comments are preceeded by semicolon, they can be at the beginning of
;   a line inline or after an instruction.

; This is metadata for the preprocessor. You MUST specify the target board.
.board=PLC14500-Nano

; These are friendly names. They allow to write code like STO MOTOR instead of STO OUT0
.io_MASTER=IN6
.io_START=IN0
.io_STOP=IN1
.io_RUN=SPR0
.io_MOTOR=OUT0

; The actual code has every line with one MC14500 instruction and paramter.
IEN MASTER
OEN MASTER

LD START    ; This is an inline comment
OR RUN
ANDC STOP
STO RUN

STO MOTOR

JMP 0
````

## Transferring to the board

Identify which COM port gets assigned to the board when plugged in and then transfer the binary file.

````
flash14500.cmd examples\example3.bin COM3
````

*Note* you should always press `RST` on the board once upload is done to clear the SPR and output latches, this will 
avoid confusion that previously stored values might cause.

If you want to load programs to the board on systems other than Windows you will need to send the `.bin` file raw on a
serial port with the following settings:

````
Baud:            9600
Parity:          None
Data Bits:       8
Stop Bits:       1
Timeout:         OFF
XON/XOFF:        OFF
CTS handshaking: OFF
DSR handshaking: OFF
DSR sensitivity: OFF
DTR circuit:     OFF
RTS circuit:     OFF
````

*Note* you must ensure DTR/RTS are off. The bootloader runs on an Arduino and the Arduino will reset when these signals
are toggled (as the serial port is open). Because of the reset delay your bootloader won't have a chance to see the
bytes you are about to spit out.

To get started with programming your board and for some ideas of new programs you can try to make yourself, read the [Programmers Guide](programmers_guide.md).

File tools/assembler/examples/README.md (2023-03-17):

## Examples

These examples are for the REV.C of the board. If you have a REV.B see the examples in the `rev.b` subfolder.

You could also consider modifying your board to match the functionality of REV.C, see the [board README](../../board/README.md)
for more information on this simple modification.

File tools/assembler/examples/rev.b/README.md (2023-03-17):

These examples are suitable for REV.B boards because they rely on an input (usually IN6) to drive the 
IEN and OEN instructions. This is due to the inability of an unmodified REV.B to read RR as an input.

If you have followed the instructions to modify your REV.B board to match REV.C (where RR is mapped
to the I/O space), you can run either this version of the examples of the ones in the parent folder (and
save IN6 for other uses).

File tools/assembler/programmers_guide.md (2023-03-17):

# PLC14500 Programmmers Guide

In this guide I will assume you are familiar with Ladder Logic diagram symbols. If these are new to you, I suggest you
first familiarize with the symbology. One good starting point is this
Wikipedia [article](https://en.wikipedia.org/wiki/Ladder_logic).

I will also assume you have assembled and tested the board following the instructions in the [READ.me](../../README.md)
file.

## The Board

### Clock Modes

Before heading into the actual programming of the board, let's familiarize with the hardware. On the top side of
the board you have two switches labelled `HI/LO` and `RUN/STEP` respectively. These control the clock generator. In run
mode the clock runs freely and can be configured between two speeds. `HI` is the "normal" running speed, which is
suitable for running programs and see inputs and outputs being processed timely. `LO` is a 1Hz clock which is mostly
suitable for a majestic display of blinking lights. If you run your program at this clock speed remember you might need
to wait seconds between applying inputs and seeing the effects on the output so, generally, you won't use it for testing
purposes.

In `STEP` mode the clock generator is stopped, so `HI/LO` has no effect. You will be providing clock pulses by
pressing the `STEP` button. This mode is very useful for following your program step by step and seeing exactly how the
various registers change as instructions are executed.

On the board you will find the `RST` button. This resets the Program Counter to zero and also clears all outputs and
the `SPR` registers. It's always a good idea to press `RST` after uploading a new program, this will ensure the program
starts from a clean state and is not affected by the settings left by the previous one.

*Note* the Program Counter is reset to zero when you press `RST` but, due to the nature of the counter, you won't see
this relected in the `ADDR` bus until you `STEP` once.

### Inputs/Outputs

The board provides 7 "inputs". They are not actual external inputs but a combination of switch and button that can be
used to simulate an external "Normal Open" or "Normal Closed" switch or button. By moving the switch you can change the
input "normal" state to either on or off, as shown by the related LED on the board (`IN0-IN6`). The button always
negates the current status. So, for instance, if you set the switch so that the input in on, by pressing the button it
will go off.

Similarly, the board provides 7 outputs which are LEDs (`OUT0-OUT6`) that can be set on or off under software control.

### Onboard Timer

There is a timer onboard that can be set from a short, about 0.5s, duration to about 10s through `RV1`. This timer is
triggered by an additional output, not available as a general output (`OUT7`). The output of the timer is wired to an
input which also cannot be set like the others with the switch and button (`IN7`).

### Status LEDs

There is no shortage of LEDs on the board. The `ADDR` and `DATA` section show the status of the RAM Address and Data
bus. Here you can see the location in the program being executed and the actual instruction and its argument.

The `J`, `RR` and `W` LEDs show the internal status of registers in the MC14500. They are respectively Jump, which goes
high when a `JMP` instruction is executed; `RR` which contains the result of the last operation; `W` which goes high
when a `STO` instruction writes to the outputs.

The rest of the LEDs should be self-explanatory as they give a visual feedback on the status of the switches (such as)
`LO`, `HI`, `R` for `RUN` and `ST` for step.

## Reading Inputs and controlling outputs

In this first example we will be simply reading the status of one of the inputs and mirroring it to an output. A ladder
diagram for such application would look something like this:

example_1

This can be translated to MC14500 assembly (with some extra code, we will get to that in a moment).

````
.board=PLC14500-Nano

IEN IN6
OEN IN6

LD  IN0
STO OUT0

JMP 0
````

The `.board` directive is metadata that serves the purpose to tell the assembler on which type of board we want to run
our code. This will have an effect on the generated bytecode as well as will provide relevant errors should some part
of the program make use of features not available in a certain board type.

The next two instructions `IEN` and `OEN` are the two intruders that don't appear in our ladder diagram. These
instructions
stand for `Input ENable` and `Output ENable`. They are a powerful construct that allows to build conditionals that, in
practice, surf over (skip) a block of code. But, for the time being, let's not digress into this. At this stage it's
enough to know that, after reset, the MC14500 "disables" its input and output or, in other words, ignores any actual
value read from the inputs and any write operation to the outputs. This is a bit unfortunate as it means we must have
such instructions in every program or the program would do nothing at all. For simplicity, we tell the MC14500 to
enable input/output operations on the status of input IN6, so we will need to make sure this is flipped to ON. This
is not how usually programs are written, as this wastes one input. However, for simplicity, the examples in this guide
will use this construct until logical operations are explained later.

The next two lines are the actual representation of our ladder diagram. The `LD` instruction will load the value of IN0
into the only register `RR`. After this, `STO` will store the value in `RR` into `OUT0` so, in practice, OUT0 will
reflect the status of `IN0`.

The last instruction `JMP 0`, jumps at the start of the program. **Note!** The PLC14500-Nano doesn't have a pre-settable
Program Counter, for this reason it allows jumping only to 0. The assembler will error if you try to do otherwise.
However, worry not, with the `IEN`/`OEN` instructions and the `SKZ` conditional there are plenty of options to have more
complex flows than just a single loop.

Let's go ahead and assemble the program. I'm assuming here you downloaded the release zip and unzipped it in a folder.

````
asm14500.exe examples\example1.asm
````

If you now look into the `examples` folder you should have a 256-bytes file named `example1.bin`. The file is 256 bytes
because that's what the bootloader of a PLC14500-Nano expects, your program is just 5 bytes long, the rest has been
padded with `0x0F`. You can see this with a binary editor:

````
Offset(h) 00 01 02 03 04 05 06 07 08 09 0A 0B 0C 0D 0E 0F
00000000  EA EB 81 88 0C 0F 0F 0F 0F 0F 0F 0F 0F 0F 0F 0F  êë.ˆ............
000000E0  0F 0F 0F 0F 0F 0F 0F 0F 0F 0F 0F 0F 0F 0F 0F 0F  ................
.....
000000F0  0F 0F 0F 0F 0F 0F 0F 0F 0F 0F 0F 0F 0F 0F 0F 0F  ................
````

Before we can test the program on the board we will need to identify which COM port gets assigned to our board. Also,
ensure you followed the board assembly instructions and burned the bootloader into the Arduino Nano. The easiest way
to find out the right COM port is to open the Arduino IDE, open the `Tools\Port` menu and take a note of what ports
are available (possibly none), then plug in the PLC14500-Nano and check again `Tools\Port` to determine the new one
that appeared. In this guide I will assume `COM3`, adjust examples as needed.

Let's now load the assembled program to the board:

````
flash14500.cmd examples\example1.bin COM3
````

You should see the `ADDR` and `DATA` LEDs on the board flashing for a few seconds, wait the command to complete and then
press the `RST` button on the board to ensure it's running. Also make sure the two switches on top are set to `HI` and
`RUN` respectively. This ensures the clock is running at normal speed.

To test the program make sure `IN6` is switched to on (remember, this reflects the input/output enable of the MC14500),
if you now press momentarily the `IN0` button you will notice the `OUT0` LED will follow.

Go ahead and turn off `IN6`, now regardless of the state of `IN0` the `OUT0` will not change.

Congratulations! You wrote your first PLC14500 assembly program! In truth, it could be the second if you did the
smoke test in the assembly instructions, but this is the first one you, hopefully, understand.

## Logic operations

At this stage you might be thinking: surely that was a lot of soldering and typing to just get a LED controlled by a
button, I know how to do that with a button and a LED! And you are right, it gets worse though. The next example won't
change things much, it will show what you could do with two buttons and a LED. However, this will provide the foundation
for more advanced setups not achievable by wiring alone.

The MC14500 provides instructions to perform logical operations. All logical operations are performed between the `RR`
register value and the input value provided as argument. Below is an example program that will switch on `OUT0` only if
both `IN0` and `IN1` are on.

````
.board=PLC14500-Nano

IEN IN6
OEN IN6

LD  IN0
AND IN1
STO OUT0

JMP 0
````

This is actually very similar to the previous example, just with the addition of the `AND IN1` line. This command will
take the value currently in the `RR` register (`IN0` in this case) and do a logical `AND` with the value in `IN1`, the
result will be stored in `RR` and, on the next line, stored in `OUT0`.

If you assemble and load the program above you will notice you need to have both `IN0` and `IN1` on for `OUT0` to go on.

There's not much point in providing examples for other logical operations, there will be many occasions later on to use
them directly in various applications. I will just list below all logical operations provided by the MC14500 for
reference.

| Instruction | |
|---|---|
| AND | RR = D AND RR |
| NAND | RR = !Data AND RR |
| OR | RR = Data OR RR |
| ORC | RR = !Data OR RR  |
| XNOR | RR = !(Data XOR RR) |

## IEN/OEN

We've seen, out of necessity, `IEN` and `OEN` instructions above. In the examples so far both commands were just run at the
start of the program and the argument was always `IN6`. This is perfectly fine for many programs you might want to write
on your trainer board. However, not only this wastes one input, it also fails to make use of the instructions for their
intended purpose. To enable unconditionally inputs and outputs, as we do in these simple examples, you can do the following:

````
  ORC RR
  IEN RR
  OEN RR
````

`RR` refers to the result register of the MC14500 which is, conveniently, mapped as an input, so it can be addressed
by instructions as if it was an input/output. To understand this block of code, refer above to the `ORC` operation in the table above. This is
an `OR` operation between the value in `RR` and the complement of whatever is currently on the `RR` input which, of course,
is `RR` itself. This means that, regardless of the value of `RR` we will always be making an `OR` operation between the
value and its negation, ie always between a `0` and a `1`, hence the result will always be `1`.

If you really want to dive deeper, you might think this is faulty because, on reset, inputs are disabled so the `ORC`
wouldn't be able to read `RR`. This is true, however, at reset `RR` is initialized to `0`, and reading an input when
inputs are disabled reads always a zero. For this reason, at reset, we will still be making an `OR` between `0` (`RR`)
and the complement of the read input, which will result in a `1`.

**NOTE** Boards up to REV.B (included) didn't have RR mapped to the I/O space and, for this reason, were not able to 
use `IEN`/`OEN` instructions driven by the application status, as described here. If you have a `REV.B` board you can easily enable this 
functionality with a simple mod. See instructions in the [/board](../board) folder. If you don't wish to modify your 
board, please keep using the `IEN IN6`/`OEN IN6` construct also in the code in the next sections. You will not be able,
however, to follow more advanced techniques to create `IF`/`ELSE`/`ENDIF` blocks.

## Latch and Reset

With the next example things will start to get more interesting and will move a step further from something that can be
achieved by just wiring buttons and LEDs. From here I will start also to introduce the examples in terms of real life
applications instead of abstract "the output will be on when this and that happens".

For this example we will consider a common scenario in industrial machines where we have a motor controlled by two
buttons,
one to start it and one to stop it.

I will take the occasion of our first real-life scenario, to digress and introduce a feature of the assembler that will
make your programs easier to understand and maintain. The assembler metadata allows to provide friendly names for the
inputs and outputs of the board, these names can then be used throughout the code instead of the input/output names.
This
will not only make the code much easier to read and understand, it will also allow to change the inputs/outputs assigned
to each function a breeze with no risk to forget to change them somewhere in the code.

Friendly names are declared in the assembly file like this:

````
.io_SWITCH_A=IN0
.io_SWITCH_B=IN1
.io_MOTOR=OUT0
````

This will then allow us to use them throughout the code like:

````
LD SWITCH_A
AND SWITCH_B
STO MOTOR
````

We will see a practical usage soon, but before we can implement our machine control buttons there's one more notion I
need
to introduce which is the Scratchpad RAM (`SPR` in short). The `SPR` is composed of 8 bits mapped as inputs and outputs
where the outputs are always looped back to their respective inputs. In other words, if you write something to `SPR0`
you
can read it back later on in the program. This is not true for `IN` and `OUT` that are not looped back (writing a value
in `OUT0` doesn't affect `IN0`, as one would expect.). The `SPR` is useful to store values we want to persist and use
in different parts of our program.

The ladder diagram for an industrial motor start/stop control would look like this:

example_3

`START` is our start button and `STOP` the stop button. `MOTOR` is, you guessed it, the motor. Things get interesting
with `RUN`. This is not an actual button or actuator, this represents what you would achieve with a relay. When the coil
of the hypothetical `RUN` relay is energized the `RUN` contactor would be closed. This, in practice, will keep energized
the `RUN` relay coil even when `START` is released. This allows us to achieve one of the goals: latch `RUN` when `START`
is pressed. The `STOP` button (normally closed), will de-energize `RUN` when pressed and, as a consequence, reset the
latch
completing the needed functionality. The bottom rung in the ladder simply applies the `RUN` contactor to the motor.

As you might have guessed by now, `RUN` is neither an input nor an output, it's just a value we need to store and, as
we just learned, the `SPR` is there exactly for this purpose. The code below implements the described start/stop logic.

````
.board=PLC14500-Nano
.io_START=IN0
.io_STOP=IN1
.io_RUN=SPR0
.io_MOTOR=OUT0

ORC  RR
IEN  RR
OEN  RR

LD   START
OR   RUN
ANDC STOP
STO  RUN

STO  MOTOR

JMP  0
````

I won't go into too much detail of the code as the operations are like those described previously. What is to be noted
is the usage of `RUN` (which is a label for `SPR0`) to store the status of the motor. If you assemble and load this
program you will notice that when you press `IN0` the output `OUT0` will go high. Take a moment to look at the `SPR0`
LED as well and notice how it also goes on. Pressing again `IN0` (`START`) doesn't to anything, however
pressing `IN1` (`STOP`) will switch off `OUT0` (`MOTOR`) as well as `SPR0`.

Now that you have a bit more complex program take a moment to familiarize with the step of moving from a ladder diagram
to the assembly code. You might have jumped on the chair when, above, I said "and this ladder diagram can be written as
this program", I won't blame you. However, if you look closely at the first rung `START` and `RUN` are in parallel, this
means they are passing current if one OR the other is on (`LD START` `OR RUN`). Moving towards the right of that same
rung we see that current flowing though `START` or `RUN` can't reach the `RUN` coil if `STOP` is pressed (it's a Normal
Close contact), so we need `ANDC STOP` (if stop is on, ie pressed, we will do an AND with the complement which is off,
this will always result in off, regardless of the status of `START` and `RUN`).

With a bit of exercise you should be able to read the ladder diagram from top to bottom and type accordingly the
assembly code.

## Using the timer

PLC14500-Nano comes with one analog onboard timer. The timer (`TMR-0`) can be triggered with a high pulse on `OUT7`. The
output of the timer output can be read on `IN7`. Once the timer is triggered, `IN7` will go high for a time that can be
set with `RV1`, after this time has elapsed `IN7` will go back to low until the timer is triggered again.

We can use the timer to implement, for instance, the controller for a set of lights on the staircase of a block of
flats. We will assume 4 buttons, one per floor. The desired behaviour is that which ever button is pressed will cause
the lights to turn on and, after a preset time the lights will go off.

````
.board=PLC14500-Nano

.io_BUTTON_A=IN0
.io_BUTTON_B=IN1
.io_BUTTON_C=IN2
.io_BUTTON_D=IN3
.io_LIGHT=OUT0

ORC  RR
IEN  RR
OEN  RR

LD   BUTTON_A
OR   BUTTON_B
OR   BUTTON_C
OR   BUTTON_D

STO  OUT7

LD   IN7
STO  LIGHT

JMP  0
````

The buttons handling should be clear by now, we just load each button status and OR it into a final status that we use
to trigger `TMR-0` (by storing it in `OUT7`). We then store into `LIGHT` the status of `IN7`, which is the timer output.

If you load this program you will notice that by pressing any buttons `IN0`-`IN3` will cause `OUT0` to become high.
After a time, dependent on the setting of `RV1`, `OUT0` will go off.

## I/O Map

Below is the PLC14500-Nano I/O map.

io_map

*NOTE:* Before REV.C, $7 was a general Scratchpad RAM location and the board provided no means to read RR. Having RR 
mapped to an input allows to unleash the full power of IEN/OEN operations.  If you have a pre REV.C board fear not! 
You can enable the same feature with a very simple mod, see instructions in the [/board](../board) folder.

## Next Steps

Given the nature of the board I won't include more examples in this guide as, I believe, most will build this for the
fun of writing new programs and figure out things on their own. The above should have provided enough info to
familiarize with elements specific to the board and toolchain.

I suggest you get familiar with the Motorola "MC14500B Industrial Control Unit Handbook" that provides a plethora of
information on the processor itself and on its programming model. In particular, you can find there sections on how
to implement conditionals and how to unleash all the power of the `IEN`/`OEN` instructions for conditional loops. 

Some ideas of programs you might want to try to write, in no particular order:

* Motorized gate with limit switches on open/closed and an obstruction sensor that will cause the gate to re-open.
* A two floors goods lift, with UP/DOWN buttons, sensors to ensure the doors are closed and floor switches
* A motor START/STOP controller with an over-current protection switch that will prevent restarting the motor for a
  certain time if triggered
* A delayed on timer for a bathroom fan, so that the fan only starts after some delay after the lights are on and keeps running for some time after the lights have been switched off

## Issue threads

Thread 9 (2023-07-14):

"D7" stuck at 0....W (write) LED never blinks.

wa6vpl, 2023-07-14:
Nice kit Nicola! The board appears to be working as designed, However, I am having a problem I need some help to fix....
Not able to see an output at OUT0. Analysis with O-scope and logic analyzer revealed "D7" out of the RAM is stuck at Logic 0 and the W (write) LED never blinks. Looking at the load at power-on (plugging in USB) revealed no transitions on D7. Then I removed the Nano and connected Logic Analyzer to the appropriate pins to trace: PRG, WEN, D7, D6 and GND. D6 looked OK but D7 did not toggle at all during the boot. Is this a defective Nano? I have a Rev C. board...tried to figure out from your Github site if there was something not in sync. I suppose a simple program could be tried to toggle pin12 (D9) to see if "D7" is really stuck...but I am unsure if I have the smarts to reload the monitor.
Any ideas where to look? Thanks, Jim

nicolacimmino, 2023-07-14:
Hi and thanks!

REV.C is good, it's the latest and actually what the vast majority of kits have been shipped with.

The 14500Mon is simply an Arduino sketch (it includes both the bootloader and monitor functionality), so as long as you have an Arduino IDE you should be able to load it. ( https://github.com/nicolacimmino/PLC-14500/tree/master/14500mon )

It seems like it could be the Nano. If you have a spare one perhaps you could try to load there the 14500Mon.

I'm travelling at the moment for 2 weeks, but PM me if you like I can send you a spare one on my return.

wa6vpl, 2023-07-14:
Thanks for quick reply.  I am familiar with using latest IDE and programming
other types of boards (Uno and Mega).  So will give it a try and let you
know results.  I do not have any spare Nano's, so will be very careful
checking pins and running test sketch.

  _____

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

wa6vpl, 2023-07-18:
I was wrong with saying I could not get things working.  Everything is just
fine.  I was not using the assembler correctly thus the in and out ports
were not letting me set the Result Register.  It paid, for me at least, to
read as much of the documentation as possible on your Git Hub. I should have
looked closer at the schematic to determine each port's address.

I needed to turn the board around 180 degrees so that the LSBs were to the
right. That makes it easier (for me) to read the program counter, op code
and port address when single stepping. This will date me perhaps.  Going
back to the  late 1970's my early 8080 and Z80 kit computers had lots of
LEDs and toggle switches on the front panels that were set up for LSB
starting from the right side.

Thanks again for a great design. My time revisting the old computer hardware
for the last couple of years brings back great memories of when I was a
development engineer working on process control sysems for nuclear power
plants.

Regards, Jim

 Hi and thanks!

REV.C is good, it's the latest and actually what the vast majority of kits
have been shipped with.

The 14500Mon is simply an Arduino sketch (it includes both the bootloader
and monitor functionality), so as long as you have an Arduino IDE you should
be able to load it. (
https://github.com/nicolacimmino/PLC-14500/tree/master/14500mon )

It seems like it could be the Nano. If you have a spare one perhaps you
could try to load there the 14500Mon.

I'm travelling at the moment for 2 weeks, but PM me if you like I can send
you a spare one on my return.

-
Reply to this email directly, view
<https://github.com/nicolacimmino/PLC-14500/issues/9#issuecomment-1635425049
> it on GitHub, or unsubscribe
<https://github.com/notifications/unsubscribe-auth/AQO3COUPJH2SBX2ELHDT6KLXQ
DYONANCNFSM6AAAAAA2JVQK6E> .
You are receiving this because you authored the thread.
<https://github.com/notifications/beacon/AQO3COSWMDTKEKHXPYMYGCLXQDYONA5CNFS
M6AAAAAA2JVQK6GWGG33NNVSW45C7OR4XAZNMJFZXG5LFINXW23LFNZ2KUY3PNVWWK3TUL5UWJTT
BPKNRS.gif> Message ID:
***@***.***>

nicolacimmino, 2023-08-03:
Good to hear all is working!

I had some others mentioning the bit order on the board LEDs. TBH given it's a 1-bit system I always thought of them as independent I/Os, but true that when it comes to the address bus expecially one expects to read it as a number. I currently have a quantity of boards sitting under my desk, but when I will run low I could consider flipping, with some more tweaks.

You mention revisiting old computer hardware, I am on the lookuout for ideas for a new retro kit, any thoughts on what might be cool?

wa6vpl, 2023-08-05:
Nicola,

If you make another rev/run of your 14500 design, I thought a simple I/O
header for off-board control of something....like a relay board or
opto-isolator input.  On my 14500 wire-wrapped prototype, I did just that.

I've also been going through the Z80 / Z180 retro computing thing.  Steve
Cousins' kits and the RC2014 kits are fun to build...and re-learn machine
coding and Basic again.

My very first job out of college in 1975 got me into imbeded processing
circuit design and machine coding.  I prototyped a 6800, but soon we moved
on to the Z80 for a safety control system for Nuclear Power Stations.  I
never went back to working with the Motorola 6800 or any of its varients.

Anyway, today in retirement I have acquired 2 of the Heathkit ET-3400
microprocessor trainers.  They have a monitor in ROM and there is an upgrade
box for a Tiny Basic in another ROM. One of my ET3400's was so damaged that
I could not get it to boot up with the initial display: "CPU RDY".  There
are water damaged traces and corrosion under a number of IC sockets.  I
fixed some of them but the board, overall, was trash. So....keeping with the
"Motorola" theme.....

I thought I might take the design and make my own copy...change the RAM from
2114's to something a little more modern and reuse the ROM for the monitor.
There is also MikBug and other homebrew monitors out there too.  Now, if
there were a kit using the Motorola 6802/6808 processor and a boot loader
for loading and saving code (similar to your 14500 kit).....that would be an
interesting retro computing kit.   I could send you a PDF copy of the
orginal Heathkit schematic if you are interested.

Regards, Jim

 Good to hear all is working!

I had some others mentioning the bit order on the board LEDs. TBH given it's
a 1-bit system I always thought of them as independent I/Os, but true that
when it comes to the address bus expecially one expects to read it as a
number. I currently have a quantity of boards sitting under my desk, but
when I will run low I could consider flipping, with some more tweaks.

You mention revisiting old computer hardware, I am on the lookuout for ideas
for a new retro kit, any thoughts on what might be cool?

-
Reply to this email directly, view
<https://github.com/nicolacimmino/PLC-14500/issues/9#issuecomment-1664388976
> it on GitHub, or unsubscribe
<https://github.com/notifications/unsubscribe-auth/AQO3COSRWRJRGZV256L5HZTXT
PP4RANCNFSM6AAAAAA2JVQK6E> .
You are receiving this because you authored the thread.
<https://github.com/notifications/beacon/AQO3COQQTIT2JYJXZTUUAM3XTPP4RA5CNFS
M6AAAAAA2JVQK6GWGG33NNVSW45C7OR4XAZNMJFZXG5LFINXW23LFNZ2KUY3PNVWWK3TUL5UWJTT
DGSHXA.gif> Message ID:
***@***.***>

nicolacimmino, 2023-08-05:
Hi,

thanks for your message. A I/O header on the PLC14500 is a great idea indeed, I'll keep that in mind!

That Heathkit ET-3400 sounds really interesting, I have just taken a look at it now, was not aware. If you could send the schematics or anything you have that would be great! You can mail me at nicola.cimmino@gmail.com

Nicola

Closed 2023-08-05.

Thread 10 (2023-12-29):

EEPROM not working correctly

robotalec, 2023-12-29:
I have been trying to figure this out but I have been having an issue with my REV.b board(pre and post modified to work for rev.c) where I cannot flash the eeprom. When i run the tools it runs correctly and I am sending to the right com but nothing changes on the board after restarting. I used a simple Arduino code to print all the eeprom and it shows nothing was uploaded. I thought it might be a bad nano so I tired uploading to a spare nano i had and its eeprom is blank as well. I have tried both rev b and rev c asm examples but nothing seems to load.

nicolacimmino, 2024-01-02:
Hi,

Can you make sure the 14500Mon is flashed on the Arduino before sending a bin file using the tools? The latest version is here in this repo under : https://github.com/nicolacimmino/PLC-14500/blob/master/14500mon/

You could also try to open a terminal connection to the COM port (9600,n,8,1) and use the monitor to dump the current program in EEPROM (see diasassemble and dump commands here: https://github.com/nicolacimmino/PLC-14500/tree/master/14500mon )

Let me know of any findings.

Regards,
Nicola

Closed 2024-03-11.

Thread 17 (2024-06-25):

Can't upload any programs (Uploading 14500MON works)

ProgrammingCube, 2024-06-25:
I can upload the PLCMON if I switch the Arduino IDE to use the Old Bootloader, but I can't for the life of me upload any code and I am perpetually stuck on the smoketest.asm code.

Any ideas? I'm using Windows 10 and tried powershell and cmd.

I am completely lost. I tried resetting the Arduino each time using the reset button on the arduino board itself before an upload, but still nothing.

Also, if I open the monitor via Putty ( no admin privileges ) then hitting ENTER does not work. But opening up in Tera term ( no admin privileges ), hitting ENTER works.

There is NO activity when using flash14500, either admin or not.

EDIT:
I see that I am writing to file COM13, not device COM13. Let me diagnose this.

EDIT 2:
I changed the syntax to \\.\%port% in the flash14500.cmd file, and now I see the RX light on the nano. But still, the ram chip seems to never update to what it needs to. Putty still does not work on my PC, but it does work on my work computer for some reason. I am still unable to get the ram chip to work correctly and load/run a bin file. The EEPROM seems to remain as the code in smoketest.asm. I used the monitor to verify this.

nicolacimmino, 2024-06-26:
Hi,

did you change the `mode` command few lines above too?

If the DTR is not off it will cause a reset on the Arduino every time the port is open and, because the Arduino bootloader takes some time, the sent bytes will never make it to the 14500 bootloader.

Another option is to leave the `flash14500.cmd` as it was and invoke it with `\\.\COM13` as param.

Let me know if it helps.

ProgrammingCube, 2024-06-26:
If I change the mode command to \\.\%port% OR if I change it all back to normal and do flash14500.cmd file.bin \\.\COM13, then it says "invalid parameter \\.\COM13"

This goes for both powershell and cmd

nicolacimmino, 2024-06-26:
Strange (and annoying!). The only thing I can think of is to force the COM port number to one below 10 (you need to do it only once, Windows will rememember it when you unplug/replug the board).

It's buried fairly deep in Device Manager, the specific serial port properties and then advanced:

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

Hope it helps!

I am considering writing an app (probably rust) for uploading, that way one wouldn't even need to rely on RTS being off, could just wait for the bootloader to send the banner. But I had little time recently to work on this project.

ProgrammingCube, 2024-06-26:
I got it working!
This was quite an issue, let me work backward and see if something is wrong with my methodology...

nicolacimmino, 2024-06-29:
This is really strage, I had another customer who had issues and eventually a port number below 10 helped. Might be some driver/driver version issue.

I also used successfully Teraterm with "send file" which has the added bonus you can keep the terminal open (but you need to exit the 14500Mon to the bootloader prompt, of course).

I'll close this issue, let me know if you need further help

Closed 2024-06-29.

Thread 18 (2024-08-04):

missing tools/assembler/bin\assembler.dart

zoul0813, 2024-08-04:
It looks like `[Bb]in/` is in the `.gitignore`, and the `tools/assembler/bin\assembler.dart` file referenced in `build_releases.cmd` is not available.

I'm attempting to make a MacOS build, but can not generate the assembler due to the missing assembler.dart

Admittedly, I'm not very familiar with Dart, and could be doing something wrong...

I've duplicated all the `.cmd` files, and converted them into MacOS friendly `.sh` files (and can provide this as a PR once I get it working - with linux compatibility included)

nicolacimmino, 2024-08-06:
Thanks for pointing this out! I have fixed and added the file.

If you manage to get a working version for the Mac that would be great, I don't have one around to test.

zoul0813, 2024-08-06:
@nicolacimmino thanks - looks like I managed to get a working build on my Mac, but after further review of the tools/assembler/README.md, I noticed it mentions an assembler-cc65 option, and links to that folder ... but that folder is also not supplied in the repo.

To test the Mac build of the assembler, I assembled the tools/simulator/examples/test_program_a.asm with it ... the resulting binary I got was 256B in size, compared to the original 13B bin that was in the folder (I also had to add the .board directive to the top - perhaps the assembler should assume the `PLC14500-Nano` unless specified?).

My newly compiled test_program_a.bin, at 256B, also appears to have set all the zeros to `0x0F` ... where the original bin had a trailing 0, mine has trailing `0x0F` up to 256B

Not sure if this is due to changes in the assembler, made after the test_program_a.bin was last compiled for the simulator?

nicolacimmino, 2024-08-07:
Thanks for pointing that out! The CC65 stuff was moved to another repo to avoid generting too much confusion, I have fixed the read.me link to point to that repo instead of the old folder.

Regarding the binaries that's exactly what the current bootloader expects: 256-byte files padded with 0x0F (which is a NOPF, so no side effects if you forget a JMP 0 at the end of your program).

I like to have the board directive mandatory so that it's always clear for what board to build, true that at the moment there is only the nano, but I have plans to develop others.

zoul0813, 2024-11-12:
@nicolacimmino PR #21 should close this issue, and provides a build_releases.sh that works on my Apple Silicon Mac

I also provided a link to the Dart Install, which is what I followed to get Dart setup on my system.

I haven't tried the cc65 stuff yet... will let you know when I do

Apologies for the delay in getting this PR in ... I got sidetracked

nicolacimmino, 2024-11-13:
@zoul0813  thanks for the PR! I merged it. In fact someone just in these days asked me about running the assembler on a Mac.

Closed 2024-11-13.

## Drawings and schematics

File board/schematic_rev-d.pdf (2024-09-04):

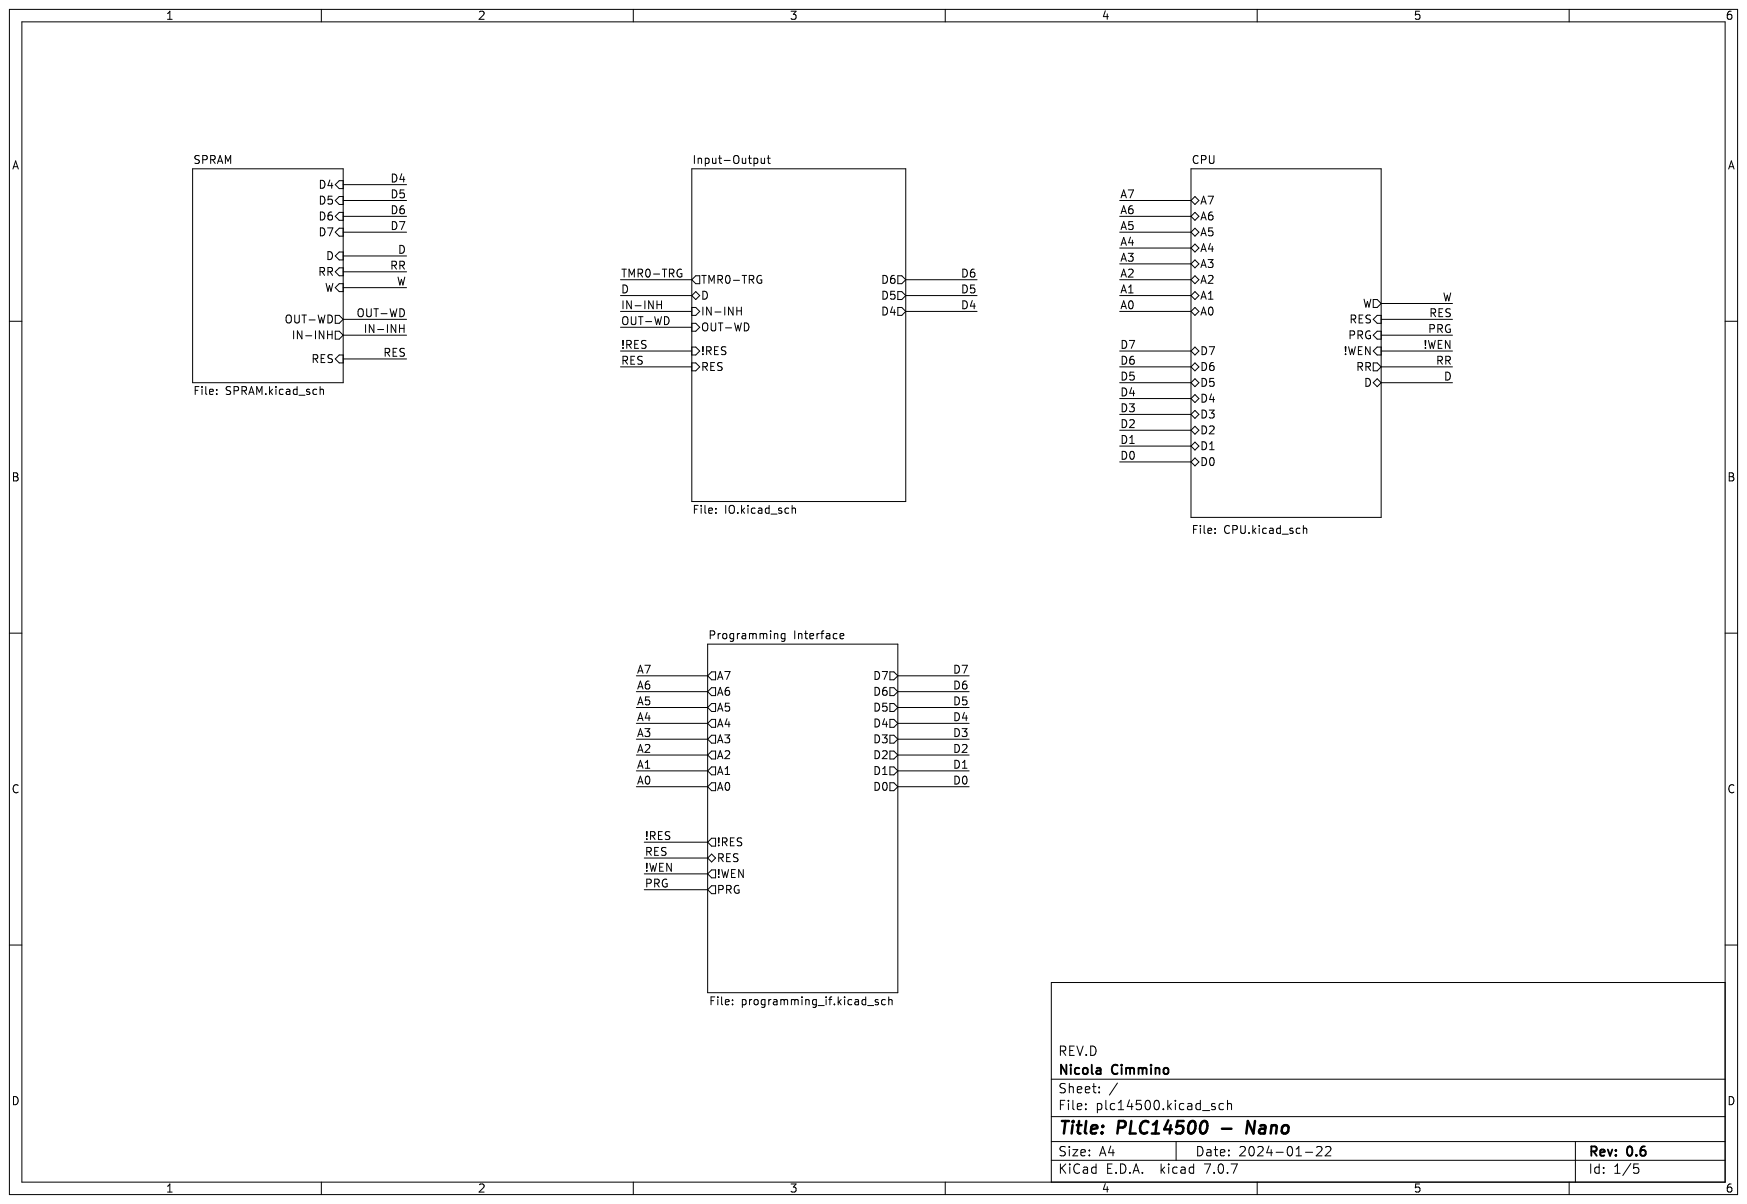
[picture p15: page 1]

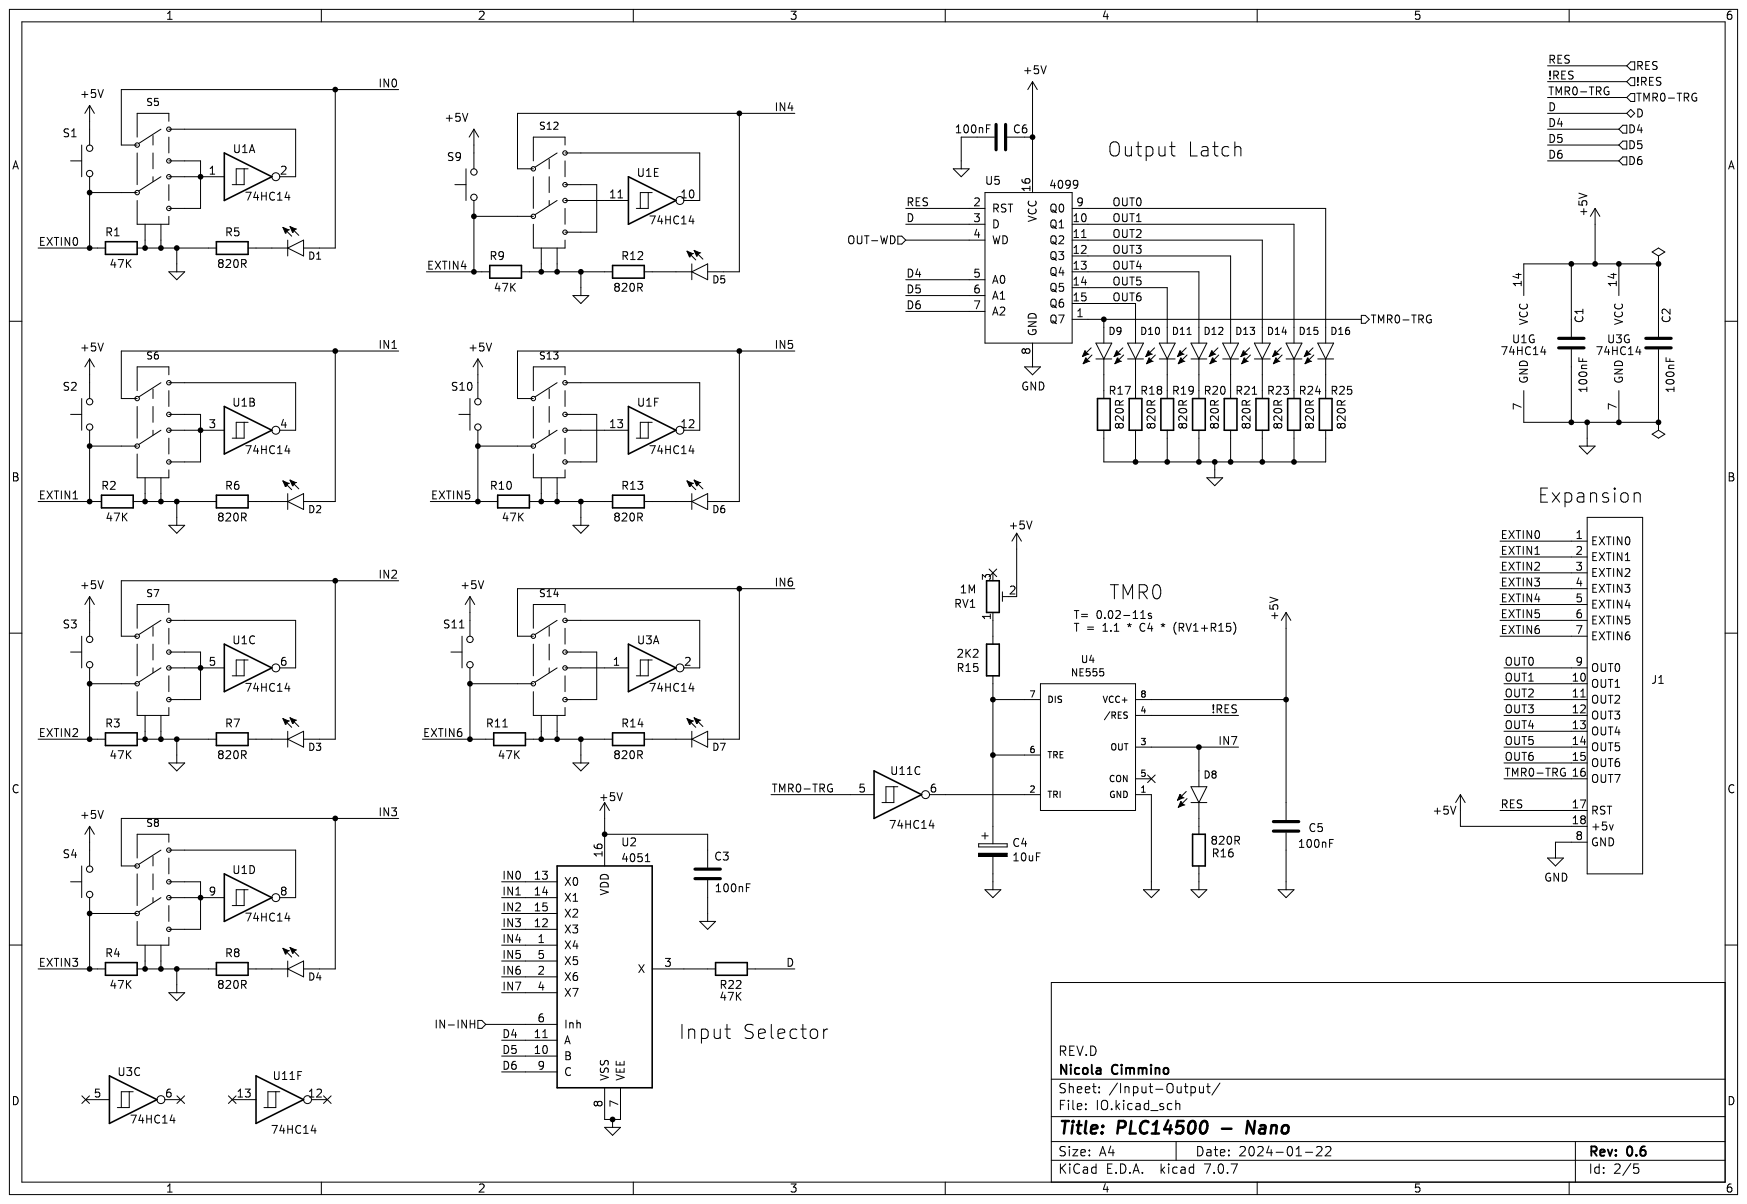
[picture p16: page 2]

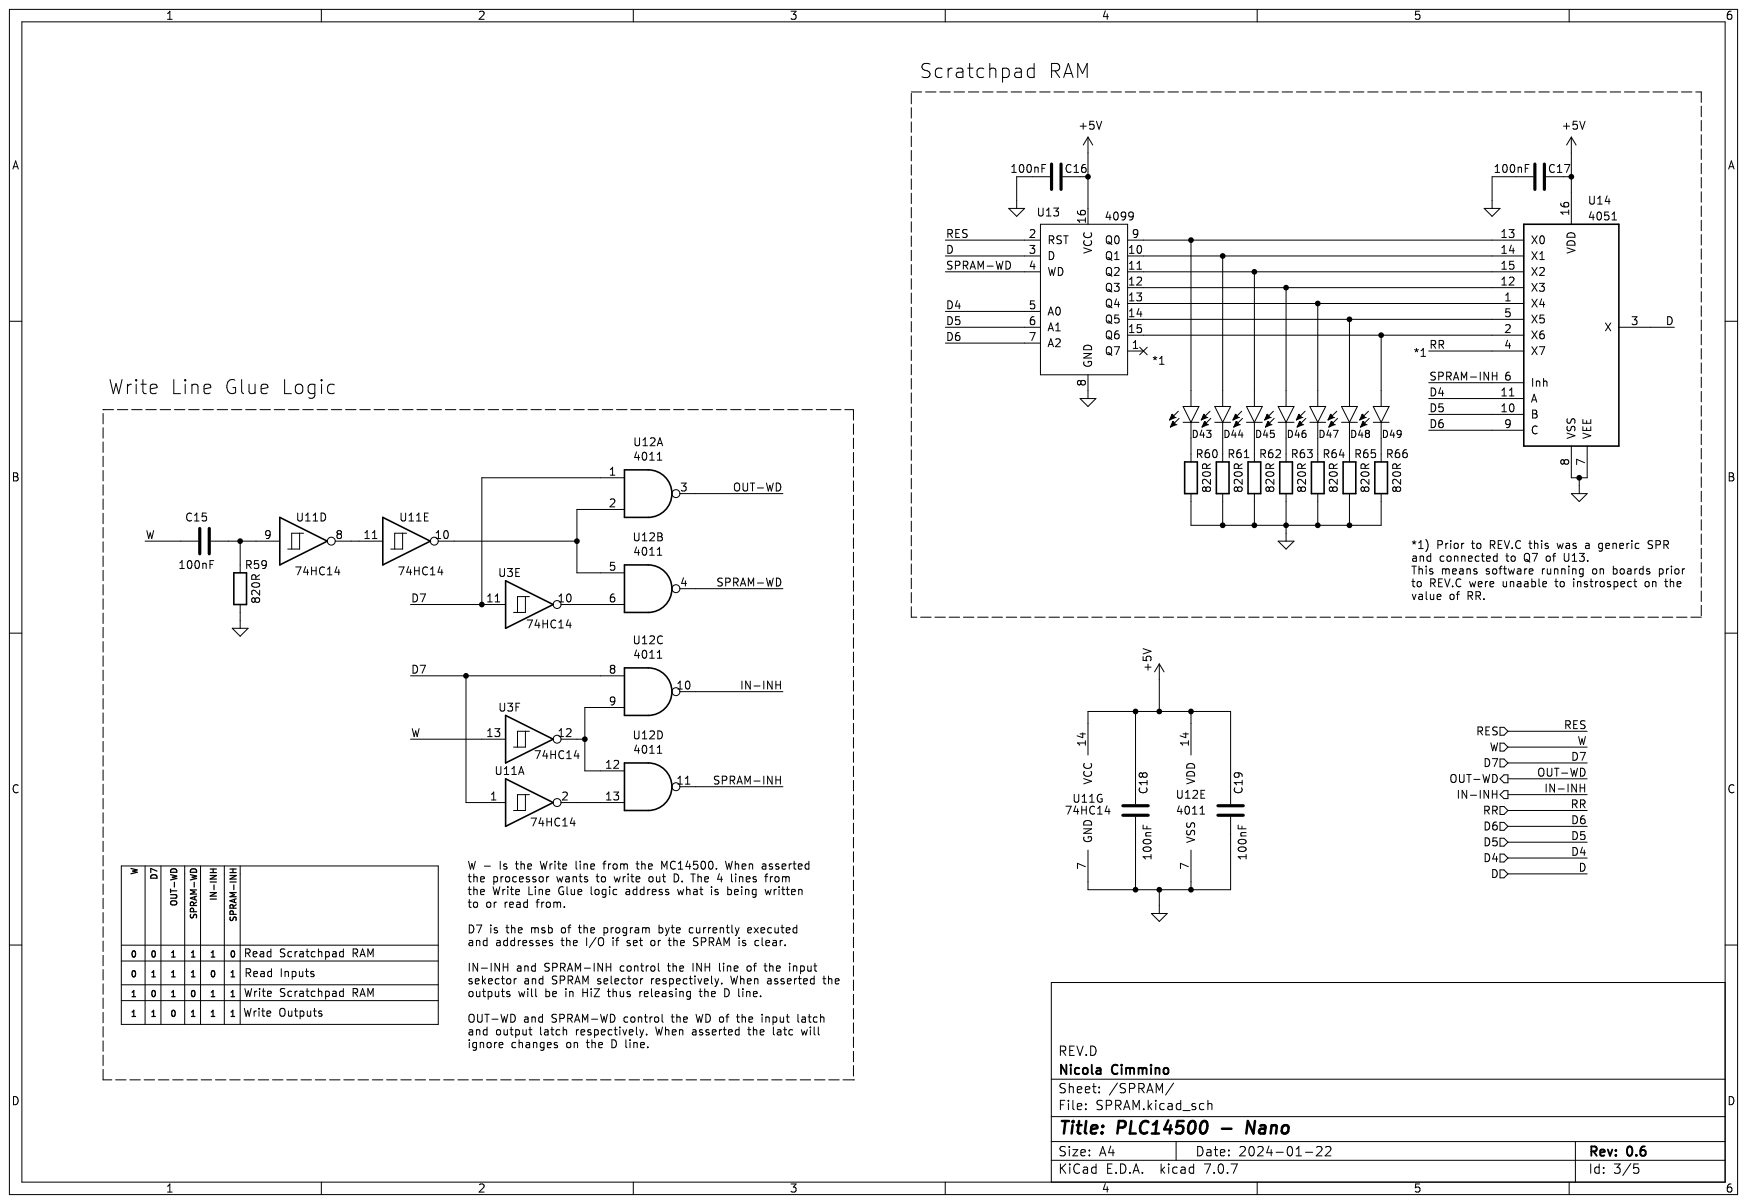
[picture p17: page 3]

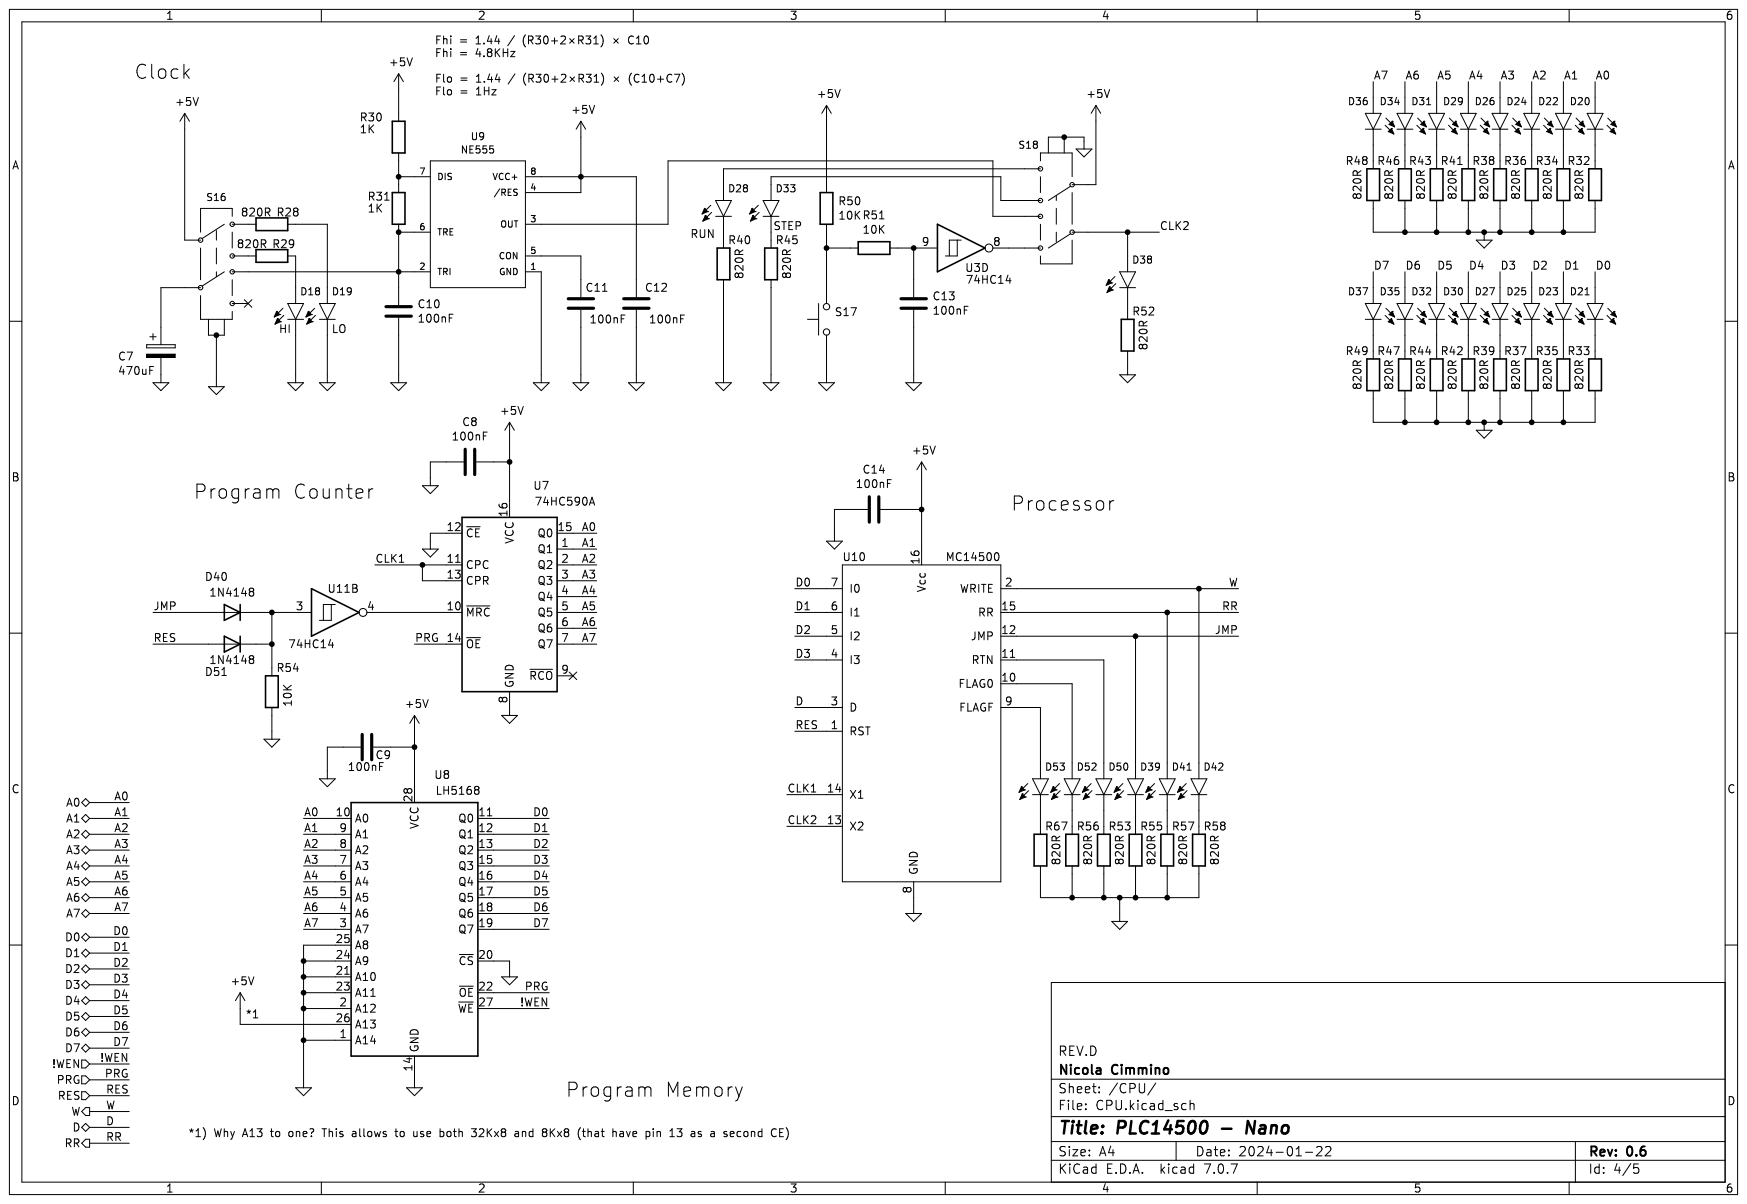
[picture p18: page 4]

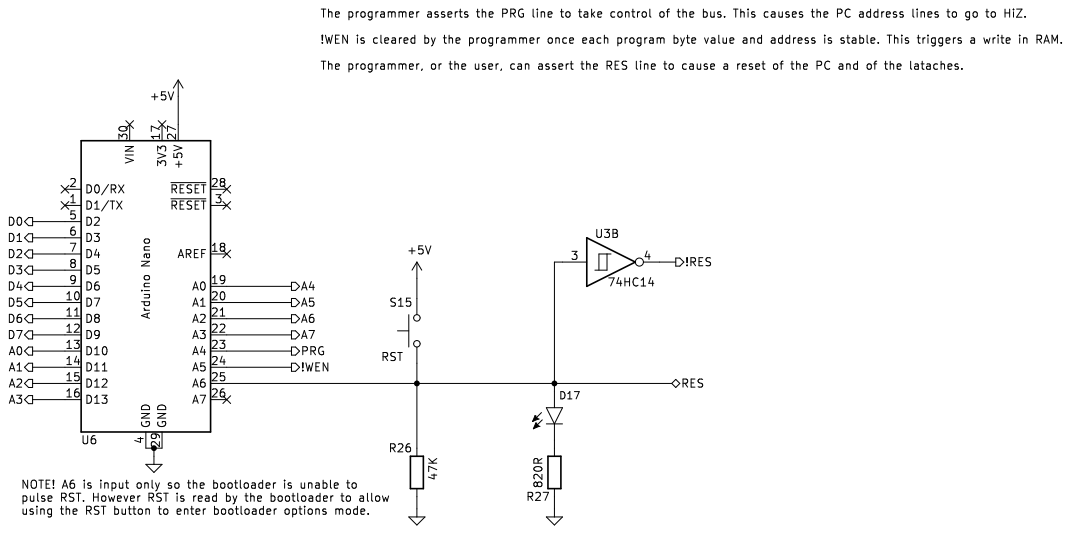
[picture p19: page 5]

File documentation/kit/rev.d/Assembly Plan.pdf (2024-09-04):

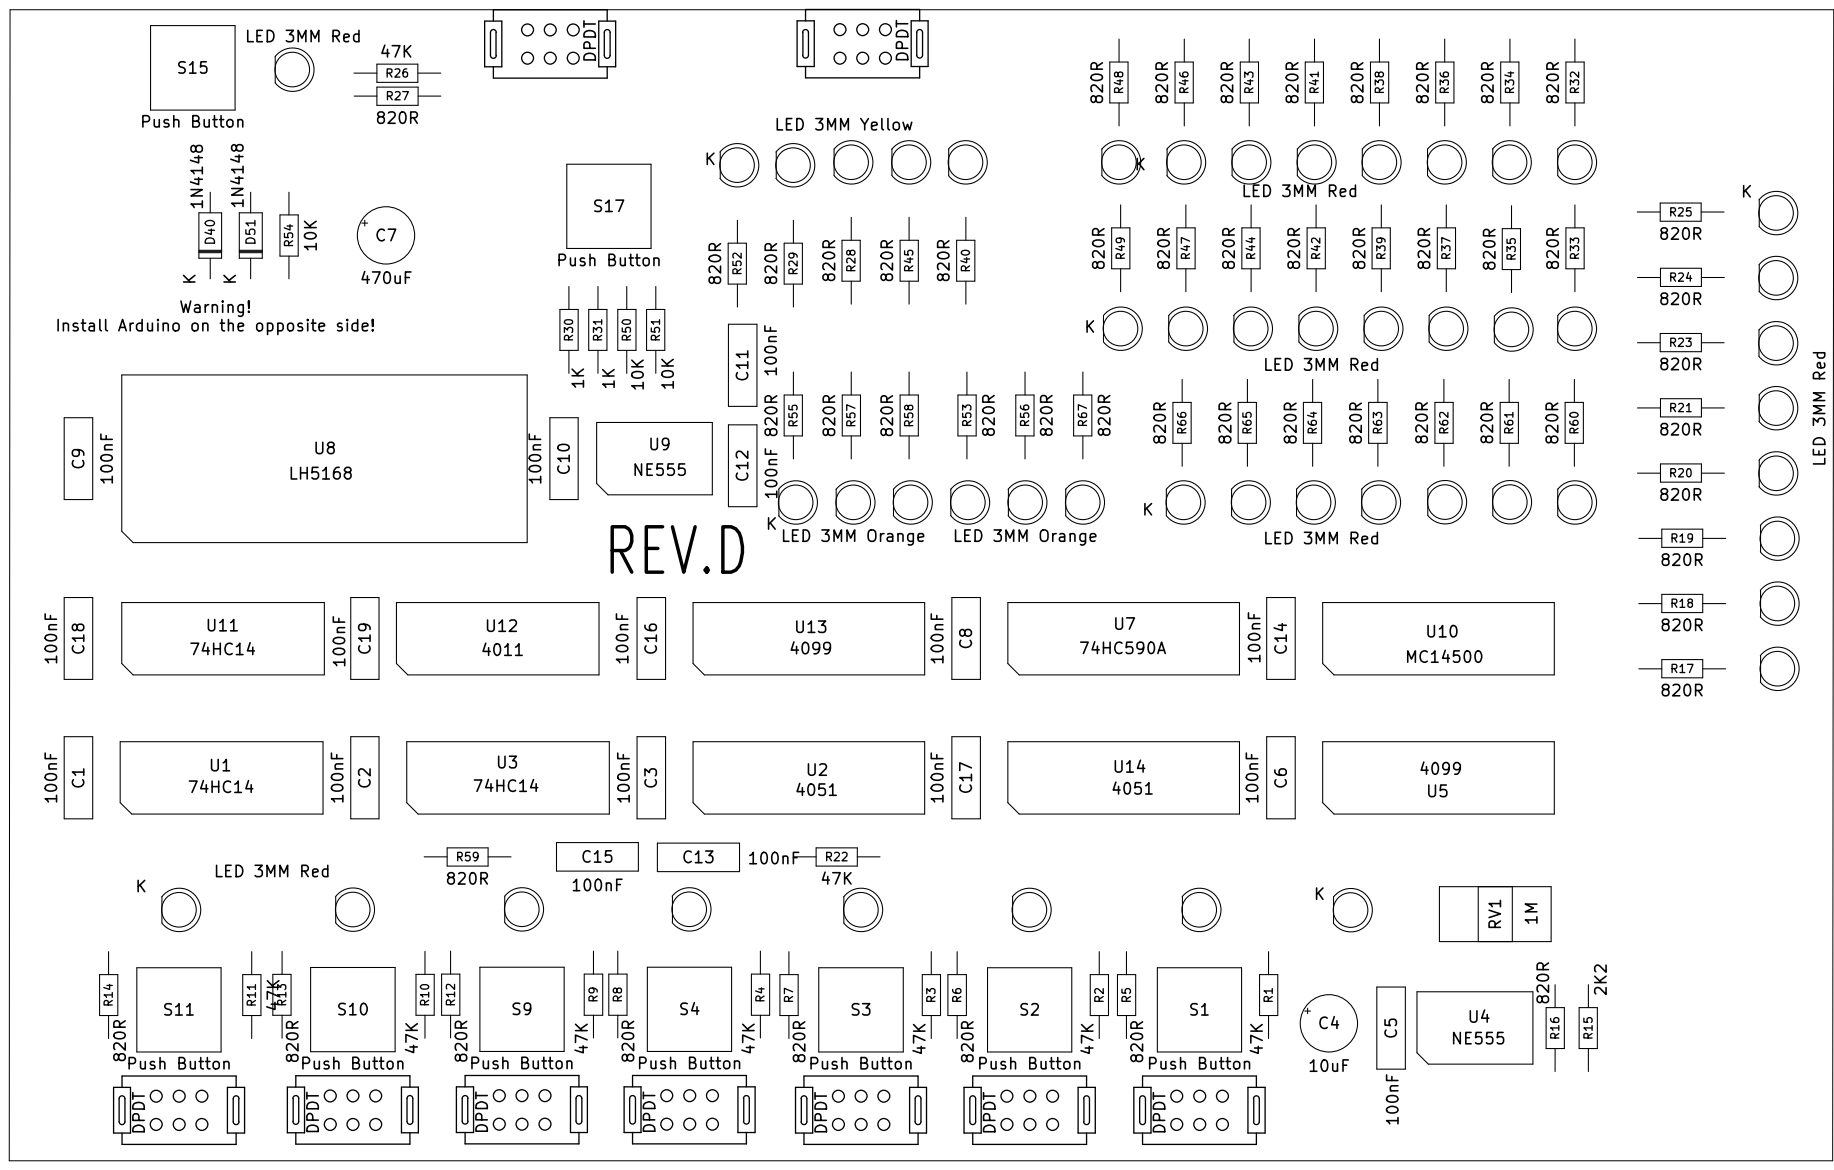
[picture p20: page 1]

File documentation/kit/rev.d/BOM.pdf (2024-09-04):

## PLC14500-Nano REV.D

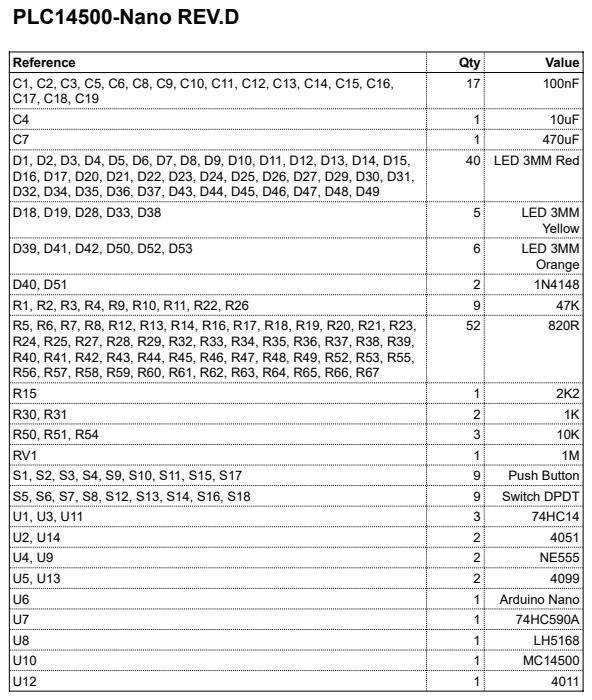
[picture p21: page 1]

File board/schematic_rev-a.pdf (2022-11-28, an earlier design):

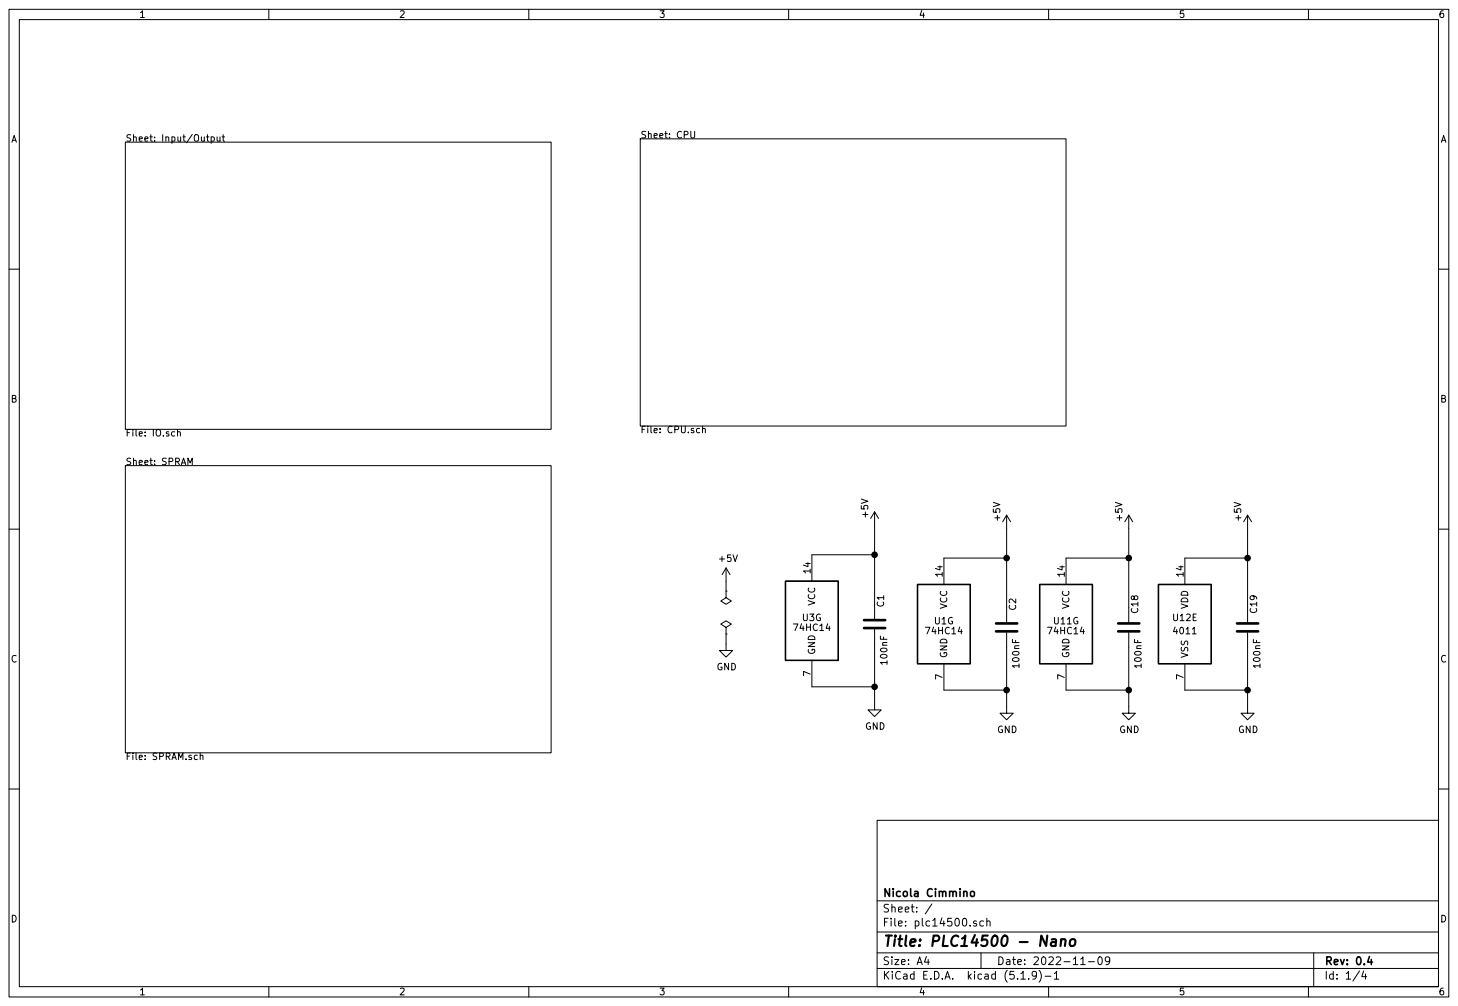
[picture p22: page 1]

File: CPU.sch Sheet: SPRAM

File: plc14500.sch Sheet: / Nicola Cimmino

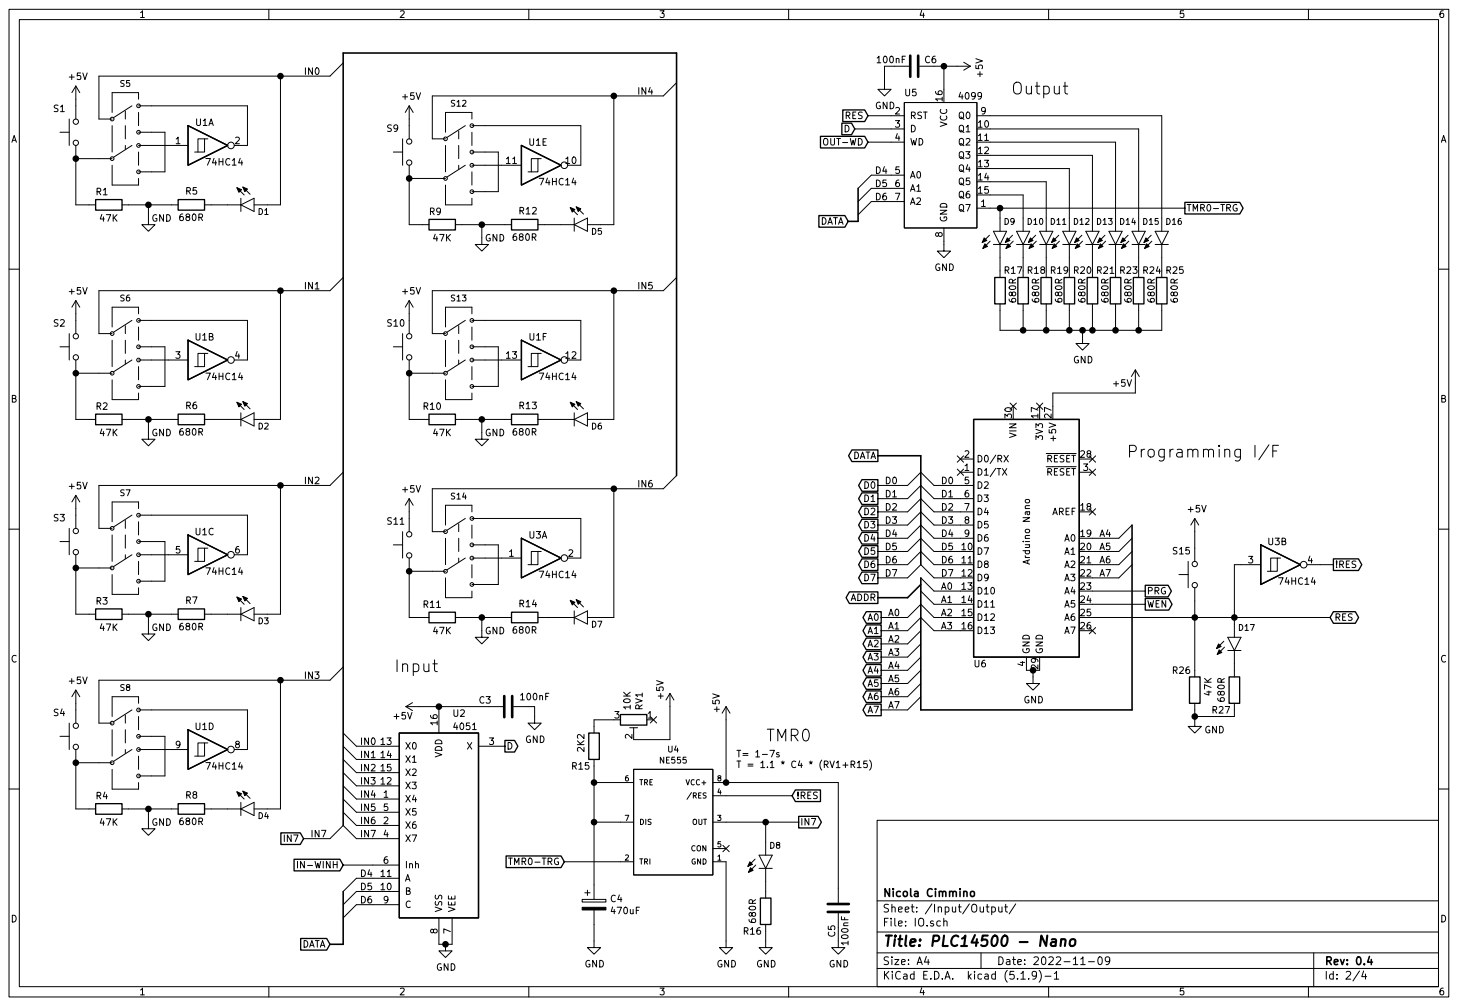
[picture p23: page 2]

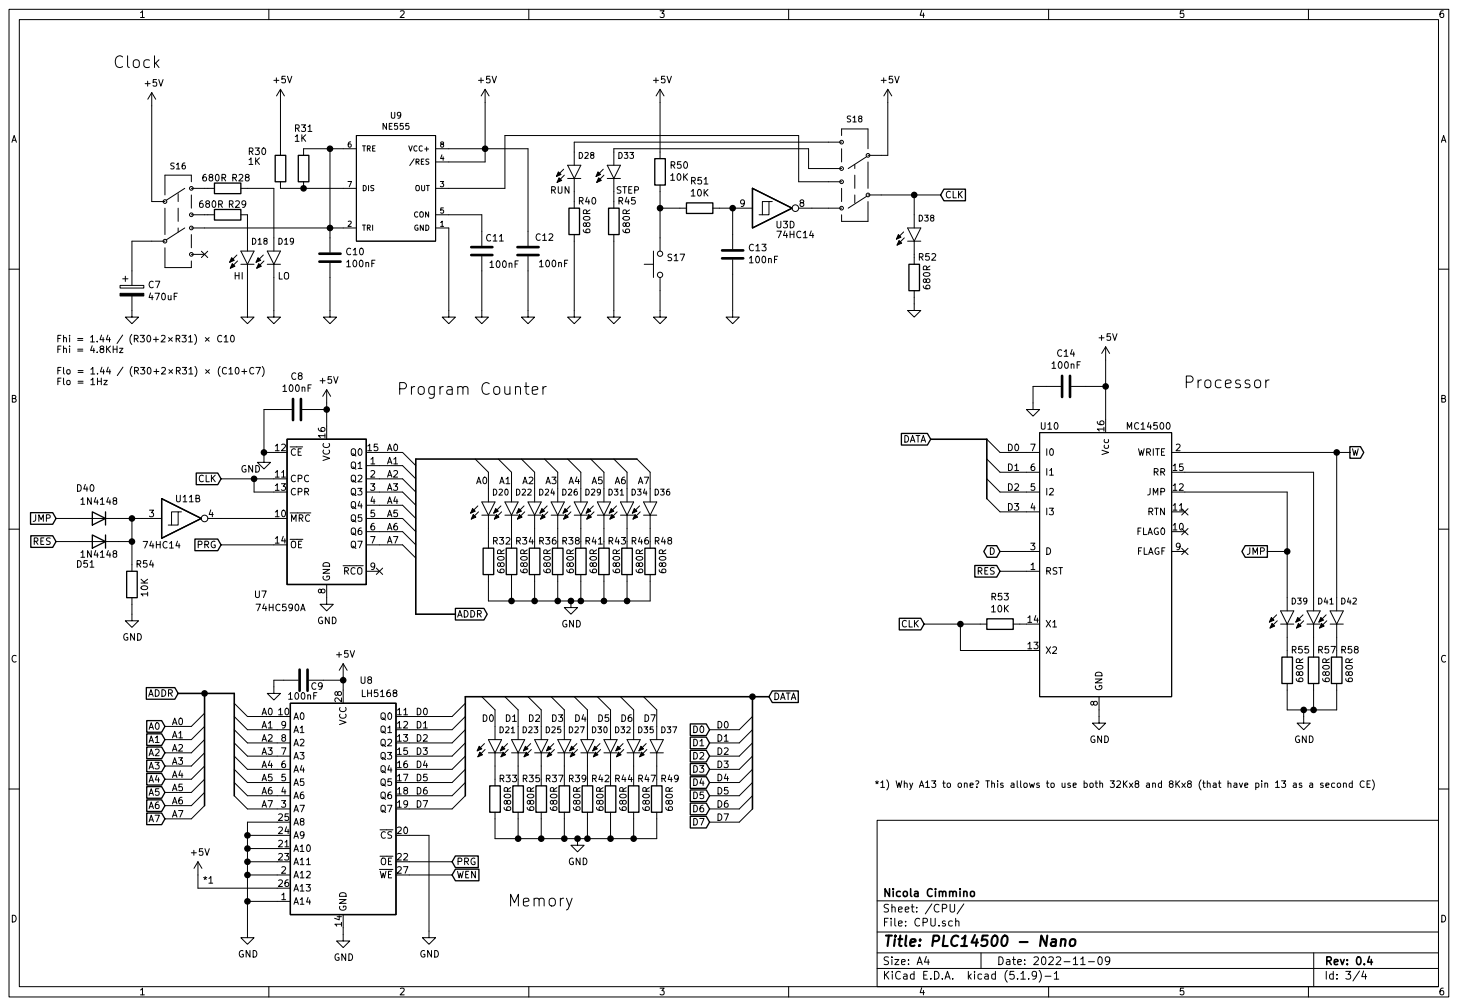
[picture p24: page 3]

File: CPU.sch Sheet: /CPU/ Nicola Cimmino R33680R

*1) Why A13 to one? This allows to use both 32Kx8 and 8Kx8 (that have pin 13 as a second CE)

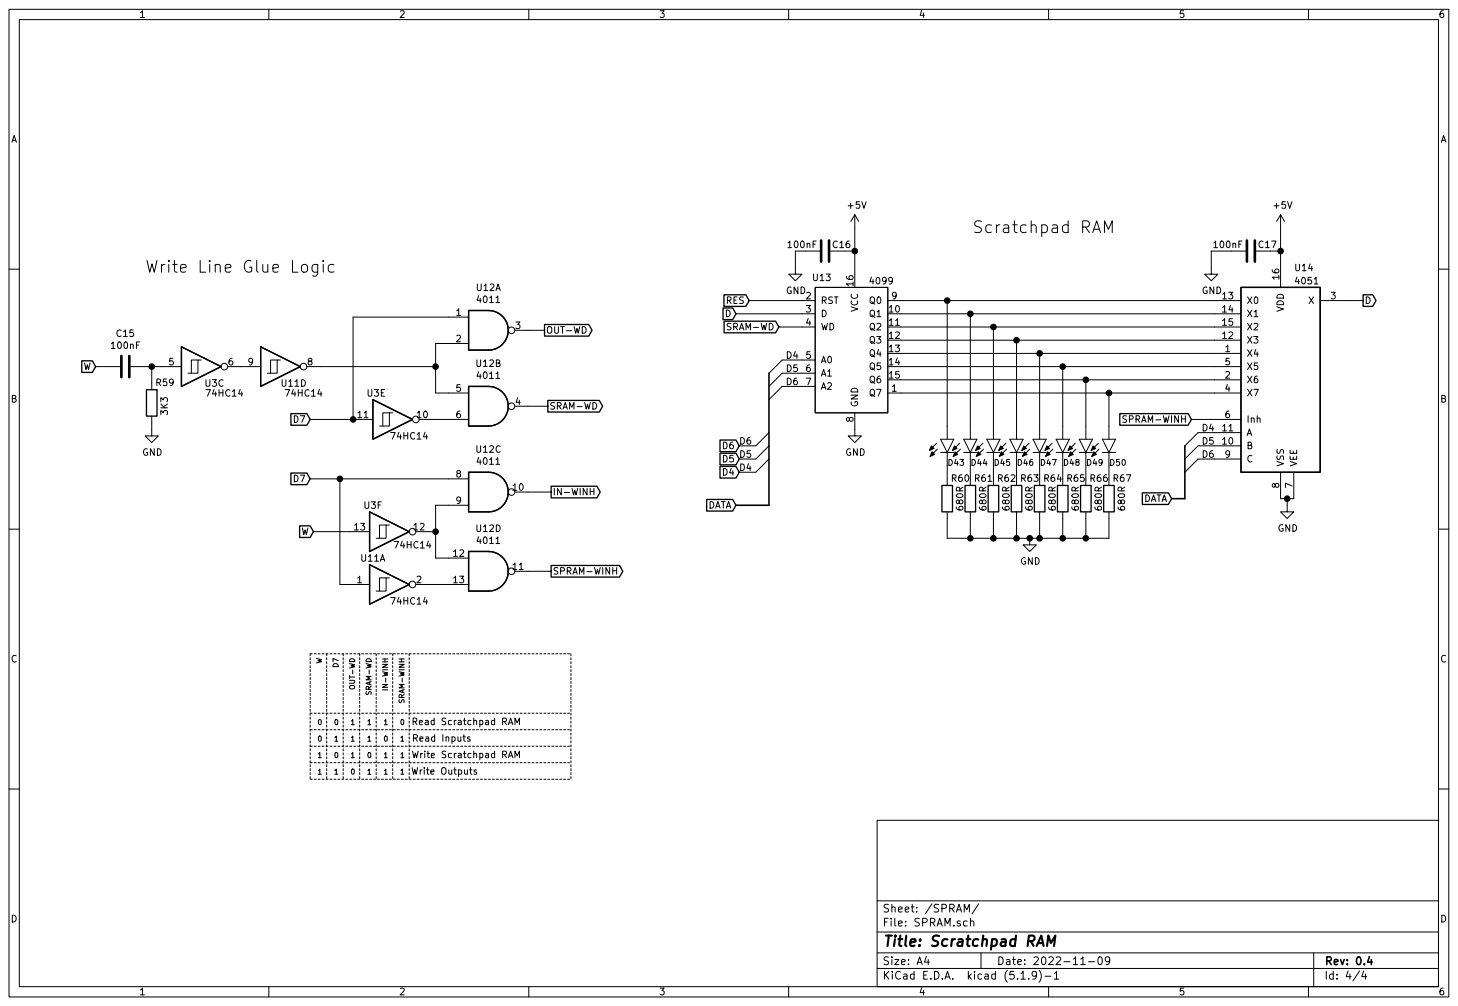
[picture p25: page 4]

0 Write Line Glue Logic

D7 1 W | OUT-WD | SRAM-WD | IN-WINH | SRAM-WINH

0 Read Scratchpad RAM | 0 | 1 1 | 1 0
0 | | 1 1 | 0 1 | Read Inputs
1 | | 1 0 | 1 1 | Write Scratchpad RAM

1 1 | | 0 1 | 1 1 | Write Outputs

File: SPRAM.sch Sheet: /SPRAM/
Id: 4/4 Title: Scratchpad RAM

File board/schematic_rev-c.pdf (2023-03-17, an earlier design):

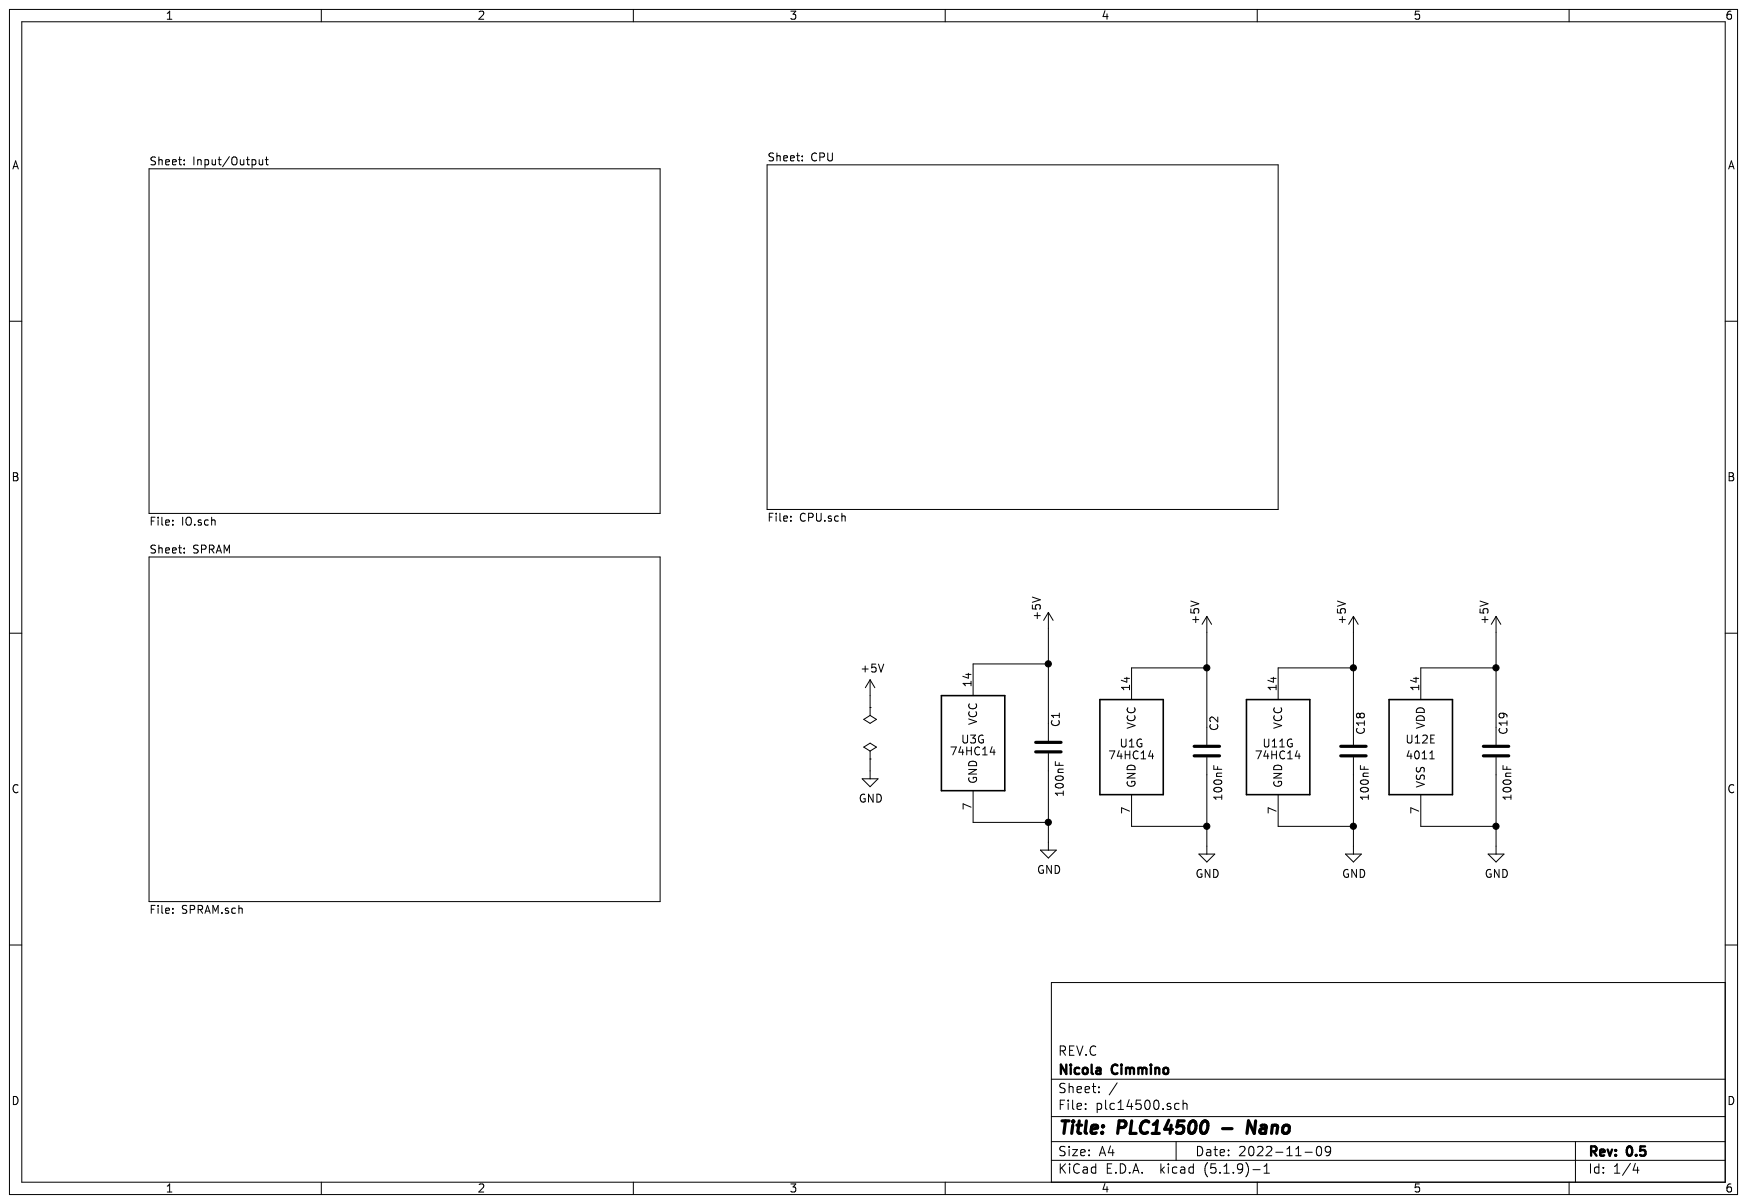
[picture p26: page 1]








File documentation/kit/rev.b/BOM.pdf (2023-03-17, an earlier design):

# PLC14500 - Nano REV.B



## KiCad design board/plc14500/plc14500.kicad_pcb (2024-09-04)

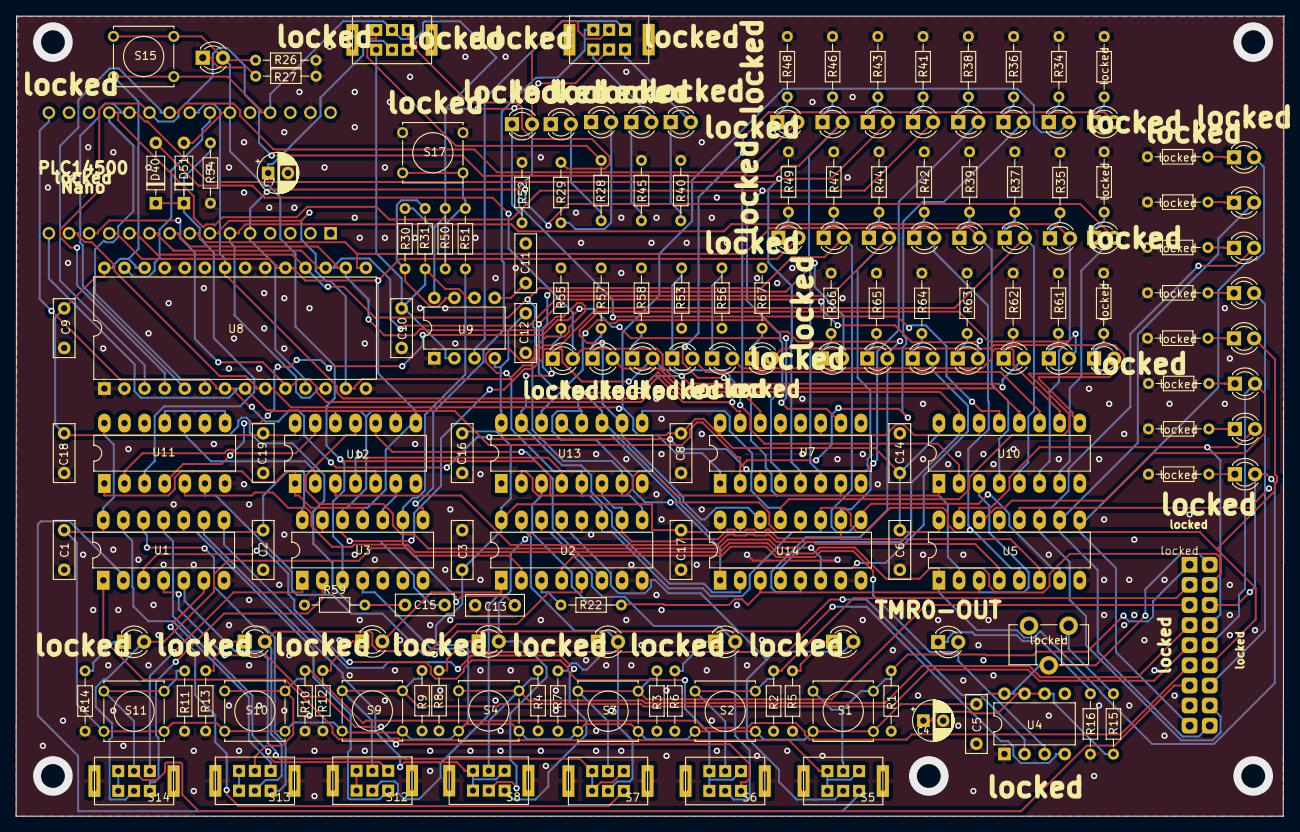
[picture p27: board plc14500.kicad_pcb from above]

Board: 2 copper layers, 160.1 x 101.0 mm, 173 parts (1 on the bottom side), 157 nets.

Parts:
C1, C2, C3, C5, C6, C8, C9, C10, C11, C12, C13, C14, C15, C16, C17, C18, C19: 100nF; C_Rect_L7.2mm_W2.5mm_P5.00mm_FKS2_FKP2_MKS2_MKP2
C4: 10uF; CP_Radial_D5.0mm_P2.50mm
C7: 470uF; CP_Radial_D5.0mm_P2.50mm
D1, D2, D3, D4, D5, D6, D7, D8, D9, D10, D11, D12, D13, D14, D15, D16, D17, D20, D21, D22, D23, D24, D25, D26, D27, D29, D30, D31, D32, D34, D35, D36, D37, D43, D44, D45, D46, D47, D48, D49: LED 3MM Red; LED_3MM
D18, D19, D28, D33, D38: LED 3MM Yellow; LED_3MM
D39, D41, D42, D50, D52, D53: LED 3MM Orange; LED_3MM
D40, D51: 1N4148; D_DO-35_SOD27_P7.62mm_Horizontal
R1, R2, R3, R4, R9, R10, R11, R22, R26: 47K; R_Axial_DIN0204_L3.6mm_D1.6mm_P7.62mm_Horizontal
R5, R6, R7, R8, R12, R13, R14, R16, R27, R28, R29, R34, R35, R36, R37, R38, R39, R40, R41, R42, R43, R44, R45, R46, R47, R48, R49, R52, R53, R55, R56, R57, R58, R59, R61, R62, R63, R64, R65, R66, R67: 820R; R_Axial_DIN0204_L3.6mm_D1.6mm_P7.62mm_Horizontal
R15: 2K2; R_Axial_DIN0204_L3.6mm_D1.6mm_P7.62mm_Horizontal
R30, R31: 1K; R_Axial_DIN0204_L3.6mm_D1.6mm_P7.62mm_Horizontal
R50, R51, R54: 10K; R_Axial_DIN0204_L3.6mm_D1.6mm_P7.62mm_Horizontal
S1, S2, S3, S4, S9, S10, S11, S15, S17: Push Button; SW_Tactile_THT
S5, S6, S7, S8, S12, S13, S14, S16, S18: Switch DPDT; SWITCH_DPDT
U1, U3, U11: 74HC14; DIP-14_W7.62mm_LongPads
U2, U14: 4051; DIP-16_W7.62mm_LongPads
U4, U9: NE555; DIP-8_W7.62mm
U5, U13: 4099; DIP-16_W7.62mm_LongPads
U6: Arduino Nano; Arduino_Nano
U7: 74HC590A; DIP-16_W7.62mm_LongPads
U8: LH5168; DIP-28_W15.24mm
U10: MC14500; DIP-16_W7.62mm_LongPads
U12: 4011; DIP-14_W7.62mm_LongPads
locked: 820R; R_Axial_DIN0204_L3.6mm_D1.6mm_P7.62mm_Horizontal
locked#2, locked#3, locked#4, locked#5, locked#6, locked#7, locked#8, locked#9, locked#10, locked#11: 820R; R_Axial_DIN0204_L3.6mm_D1.6mm_P7.62mm_Horizontal
locked#12: 1M; HORIZONTAL_POT
locked#13: PLC14500-Expansion

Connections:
+5V: C1.2, C2.2, C3.1, C5.1, C6.1, C8.1, C9.2, C12.2, C14.1, C16.1, C17.1, C18.2, C19.2, R30.2, R50.2, S1.2, S2.2, S3.2, S4.2, S9.2, S10.2, S11.2, S15.2, S16.2, S18.6, U1.14 (VCC), U2.16 (VDD), U3.14 (VCC), U4.8 (VCC+), U5.16 (VCC), U6.27 (+5V), U7.16 (VCC), U8.26 (A13), U8.28 (VCC), U9.4 (/RES), U9.8 (VCC+), U10.16 (Vcc), U11.14 (VCC), U12.14 (VDD), U13.16 (VCC), U14.16 (VDD), locked#12.2, locked#13.18 (+5v)
/!RES: U3.4, U4.4 (/RES)
/!WEN: U6.24 (A5), U8.27 (~WE)
/A0: D20.A, U6.13 (D10), U7.15 (Q0), U8.10 (A0)
/A1: D22.A, U6.14 (D11), U7.1 (Q1), U8.9 (A1)
/A2: D24.A, U6.15 (D12), U7.2 (Q2), U8.8 (A2)
/A3: D26.A, U6.16 (D13), U7.3 (Q3), U8.7 (A3)
/A4: D29.A, U6.19 (A0), U7.4 (Q4), U8.6 (A4)
/A5: D31.A, U6.20 (A1), U7.5 (Q5), U8.5 (A5)
/A6: D34.A, U6.21 (A2), U7.6 (Q6), U8.4 (A6)
/A7: D36.A, U6.22 (A3), U7.7 (Q7), U8.3 (A7)
/CPU/CLK1: U7.11 (CPC), U7.13 (CPR), U10.14 (X1)
/CPU/CLK2: D38.A, S18.2, U10.13 (X2)
/CPU/JMP: D39.A, D40.2 (A), U10.12 (JMP)
/D: R22.2, U5.3 (D), U10.3 (D), U13.3 (D), U14.3 (X)
/D0: D21.A, U6.5 (D2), U8.11 (Q0), U10.7 (I0)
/D1: D23.A, U6.6 (D3), U8.12 (Q1), U10.6 (I1)
/D2: D25.A, U6.7 (D4), U8.13 (Q2), U10.5 (I2)
/D3: D27.A, U6.8 (D5), U8.15 (Q3), U10.4 (I3)
/D4: D30.A, U2.11 (A), U5.5 (A0), U6.9 (D6), U8.16 (Q4), U13.5 (A0), U14.11 (A)
/D5: D32.A, U2.10 (B), U5.6 (A1), U6.10 (D7), U8.17 (Q5), U13.6 (A1), U14.10 (B)
/D6: D35.A, U2.9 (C), U5.7 (A2), U6.11 (D8), U8.18 (Q6), U13.7 (A2), U14.9 (C)
/D7: D37.A, U3.11, U6.12 (D9), U8.19 (Q7), U11.1, U12.1, U12.8
/IN-INH: U2.6 (Inh), U12.10
/Input-Output/EXTIN0: R1.2, S1.1, S5.6, locked#13.1 (EXTIN0)
/Input-Output/EXTIN1: R2.2, S2.1, S6.6, locked#13.2 (EXTIN1)
/Input-Output/EXTIN2: R3.2, S3.1, S7.6, locked#13.3 (EXTIN2)
/Input-Output/EXTIN3: R4.2, S4.1, S8.6, locked#13.4 (EXTIN3)
/Input-Output/EXTIN4: R9.2, S9.1, S12.6, locked#13.5 (EXTIN4)
/Input-Output/EXTIN5: R10.2, S10.1, S13.6, locked#13.6 (EXTIN5)
/Input-Output/EXTIN6: R11.2, S11.1, S14.6, locked#13.7 (EXTIN6)
/Input-Output/IN0: D1.A, S5.2, U2.13 (X0)
/Input-Output/IN1: D2.A, S6.2, U2.14 (X1)
/Input-Output/IN2: D3.A, S7.2, U2.15 (X2)
/Input-Output/IN3: D4.A, S8.2, U2.12 (X3)
/Input-Output/IN4: D5.A, S12.2, U2.1 (X4)
/Input-Output/IN5: D6.A, S13.2, U2.5 (X5)
/Input-Output/IN6: D7.A, S14.2, U2.2 (X6)
/Input-Output/IN7: D8.A, U2.4 (X7), U4.3 (OUT)
/Input-Output/OUT0: D16.A, U5.9 (Q0), locked#13.9 (OUT0)
/Input-Output/OUT1: D15.A, U5.10 (Q1), locked#13.10 (OUT1)
/Input-Output/OUT2: D14.A, U5.11 (Q2), locked#13.11 (OUT2)
/Input-Output/OUT3: D13.A, U5.12 (Q3), locked#13.12 (OUT3)
/Input-Output/OUT4: D12.A, U5.13 (Q4), locked#13.13 (OUT4)
/Input-Output/OUT5: D11.A, U5.14 (Q5), locked#13.14 (OUT5)
/Input-Output/OUT6: D10.A, U5.15 (Q6), locked#13.15 (OUT6)
/OUT-WD: U5.4 (WD), U12.3
/PRG: U6.23 (A4), U7.14 (~OE), U8.22 (~OE)
/RES: D17.A, D51.2 (A), R26.1, S15.1, U3.3, U5.2 (RST), U6.25 (A6), U10.1 (RST), U13.2 (RST), locked#13.17 (RST)
/RR: D41.A, U10.15 (RR), U14.4 (X7)
/SPRAM/SPRAM-INH: U12.11, U14.6 (Inh)
/SPRAM/SPRAM-WD: U12.4, U13.4 (WD)
/TMR0-TRG: D9.A, U5.1 (Q7), U11.5, locked#13.16 (OUT7)
/W: C15.2, D42.A, U3.13, U10.2 (WRITE)
GND: C1.1, C2.1, C3.2, C4.2, C5.2, C6.2, C7.2, C8.2, C9.1, C10.2, C11.2, C12.1, C13.1, C14.2, C16.2, C17.2, C18.1, C19.1, D18.K (C), D19.K (C), R1.1, R2.1, R3.1, R4.1, R5.1, R6.1, R7.1, R8.1, R9.1, R10.1, R11.1, R12.1, R13.1, R14.1, R16.2, R26.2, R27.2, R34.1, R35.1, R36.1, R37.1, R38.1, R39.1, R40.1, R41.1, R42.1, R43.1, R44.1, R45.1, R46.1, R47.1, R48.1, R49.1, R52.1, R53.1, R54.1, R55.1, R56.1, R57.1, R58.1, R59.1, R61.1, R62.1, R63.1, R64.1, R65.1, R66.1, R67.1, S5.8 (GND), S5.9 (GND), S6.8 (GND), S6.9 (GND), S7.8 (GND), S7.9 (GND), S8.8 (GND), S8.9 (GND), S12.8 (GND), S12.9 (GND), S13.8 (GND), S13.9 (GND), S14.8 (GND), S14.9 (GND), S16.8 (GND), S16.9 (GND), S17.1, S18.8 (GND), S18.9 (GND), U1.7 (GND), U2.7 (VEE), U2.8 (VSS), U3.7 (GND), U4.1 (GND), U5.8 (GND), U6.4 (GND), U6.29 (GND), U7.8 (GND), U7.12 (~CE), U8.1 (A14), U8.2 (A12), U8.14 (GND), U8.20 (~CS), U8.21 (A10), U8.23 (A11), U8.24 (A9), U8.25 (A8), U9.1 (GND), U10.8 (GND), U11.7 (GND), U12.7 (VSS), U13.8 (GND), U14.7 (VEE), U14.8 (VSS), locked.1, locked#2.1, locked#3.1, locked#4.1, locked#5.1, locked#6.1, locked#7.1, locked#8.1, locked#9.1, locked#10.1, locked#11.1, locked#13.8 (GND)
unnamed: C7.1, S16.6
unnamed: C13.2, R51.1, U3.9
unnamed: C15.1, R59.2, U11.9
unnamed: D1.K (C), R5.2
unnamed: D2.K (C), R6.2
unnamed: D3.K (C), R7.2
unnamed: D4.K (C), R8.2
unnamed: D5.K (C), R12.2
unnamed: D6.K (C), R13.2
unnamed: D7.K (C), R14.2
unnamed: D8.K (C), R16.1
unnamed: D9.K (C), locked.2
unnamed: D10.K (C), locked#2.2
unnamed: D11.K (C), locked#3.2
unnamed: D12.K (C), locked#4.2
unnamed: D13.K (C), locked#5.2
unnamed: D14.K (C), locked#6.2
unnamed: D15.K (C), locked#7.2
unnamed: D16.K (C), locked#8.2
unnamed: D17.K (C), R27.1
unnamed: D18.A, R29.2
unnamed: D19.A, R28.2
unnamed: D20.K (C), locked#9.2
unnamed: D21.K (C), locked#10.2
unnamed: D22.K (C), R34.2
unnamed: D23.K (C), R35.2
unnamed: D24.K (C), R36.2
unnamed: D25.K (C), R37.2
unnamed: D26.K (C), R38.2
unnamed: D27.K (C), R39.2
unnamed: D28.K (C), R40.2
unnamed: D28.A, S18.5
unnamed: D29.K (C), R41.2
unnamed: D30.K (C), R42.2
unnamed: D31.K (C), R43.2
unnamed: D32.K (C), R44.2
unnamed: D33.K (C), R45.2
unnamed: D33.A, S18.7
unnamed: D34.K (C), R46.2
unnamed: D35.K (C), R47.2
unnamed: D36.K (C), R48.2
unnamed: D37.K (C), R49.2
unnamed: D38.K (C), R52.2
unnamed: D39.K (C), R55.2
unnamed: D40.1 (K), D51.1 (K), R54.2, U11.3
unnamed: D41.K (C), R57.2
unnamed: D42.K (C), R58.2
unnamed: D43.K (C), locked#11.2
unnamed: D44.K (C), R61.2
unnamed: D45.K (C), R62.2
unnamed: D46.K (C), R63.2
unnamed: D47.K (C), R64.2
unnamed: D48.K (C), R65.2
unnamed: D49.K (C), R66.2
unnamed: D50.K (C), R53.2
unnamed: D52.K (C), R56.2
unnamed: D53.K (C), R67.2
unnamed: R15.1, locked#12.1
unnamed: R28.1, S16.3
unnamed: R29.1, S16.1
unnamed: R50.1, R51.2, S17.2
unnamed: S5.1, S5.5, S5.7, U1.1
unnamed: S5.3, U1.2
unnamed: S6.1, S6.5, S6.7, U1.3
unnamed: S6.3, U1.4
unnamed: S7.1, S7.5, S7.7, U1.5
unnamed: S7.3, U1.6
unnamed: S8.1, S8.5, S8.7, U1.9
unnamed: S8.3, U1.8
unnamed: S12.1, S12.5
unnamed: S12.3, U1.10
unnamed: S12.7, U1.11
unnamed: S13.1, S13.5
unnamed: S13.3, U1.12
unnamed: S13.7, U1.13
unnamed: S14.1, S14.5
unnamed: S14.3, U3.2
unnamed: S14.7, U3.1
unnamed: S18.3, U3.8
unnamed: R22.1, U2.3 (X)
unnamed: C4.1, R15.2, U4.6 (TRE), U4.7 (DIS)
unnamed: U4.2 (TRI), U11.6
unnamed: U7.10 (~MRC), U11.4
unnamed: C11.1, U9.5 (CON)
unnamed: R30.1, R31.2, U9.7 (DIS)
unnamed: S18.1, U9.3 (OUT)
unnamed: C10.1, R31.1, S16.7, U9.2 (TRI), U9.6 (TRE)
unnamed: D52.A, U10.10 (FLAG0)
unnamed: D53.A, U10.9 (FLAGF)
unnamed: D50.A, U10.11 (RTN)
unnamed: U11.2, U12.13
unnamed: U11.10, U12.2, U12.5
unnamed: U11.8, U11.11
unnamed: U3.10, U12.6
unnamed: U3.12, U12.9, U12.12
unnamed: D43.A, U13.9 (Q0), U14.13 (X0)
unnamed: D44.A, U13.10 (Q1), U14.14 (X1)
unnamed: D45.A, U13.11 (Q2), U14.15 (X2)
unnamed: D46.A, U13.12 (Q3), U14.12 (X3)
unnamed: D47.A, U13.13 (Q4), U14.1 (X4)
unnamed: D48.A, U13.14 (Q5), U14.5 (X5)
unnamed: D49.A, U13.15 (Q6), U14.2 (X6)

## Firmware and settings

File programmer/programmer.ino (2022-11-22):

// Programmer implements the firmware of a programmer for the PLC-14500 board.
//  Copyright (C) 2015 Nicola Cimmino
//
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
//

#define D0_PIN 2
#define D1_PIN 3
#define D2_PIN 4
#define D3_PIN 5
#define D4_PIN 6
#define D5_PIN 7
#define D6_PIN 8
#define D7_PIN 9

#define A0_PIN 10
#define A1_PIN 11
#define A2_PIN 12
#define A3_PIN 13
#define A4_PIN A0
#define A5_PIN A1
#define A6_PIN A2
#define A7_PIN A3

#define PRG_PIN A4
#define WEN_PIN A5

#include <EEPROM.h>

byte data_bus[] = {
    D0_PIN,
    D1_PIN,
    D2_PIN,
    D3_PIN,
    D4_PIN,
    D5_PIN,
    D6_PIN,
    D7_PIN};

byte addr_bus[] = {
    A0_PIN,
    A1_PIN,
    A2_PIN,
    A3_PIN,
    A4_PIN,
    A5_PIN,
    A6_PIN,
    A7_PIN};

byte rxBuffer[256];

void setup()
{

  Serial.begin(9600);
}

void loop()
{
  for (uint8_t ix = 0; ix < 255; ix++)
  {
    Serial.print(EEPROM.read(ix), 16);
    Serial.print(",");
  }

  while (!Serial.available())
  {
  }

  // We need to first take the all input data in memory
  // since the writing to the target takes 10mS we would
  // overrun the buffer if we attempted to write directly.
  for (int address = 0; address < 256;)
  {
    if (Serial.available())
    {
      rxBuffer[address] = Serial.read();
      address++;
    }
  }

  pinMode(WEN_PIN, OUTPUT);
  digitalWrite(WEN_PIN, HIGH);

  // Enter programming mode.
  // The board will release the buses.
  pinMode(PRG_PIN, OUTPUT);
  digitalWrite(PRG_PIN, HIGH);

  // Take ownership of the buses setting all
  // data and address pins as outputs.
  for (int ix = 0; ix < 8; ix++)
  {
    pinMode(addr_bus[ix], OUTPUT);
    pinMode(data_bus[ix], OUTPUT);
  }

  for (int address = 0; address < 256; address++)
  {
    writeProgramByte(address, rxBuffer[address]);
  }

  // Release the buses settings pins as inputs.
  for (int ix = 0; ix < 8; ix++)
  {
    pinMode(addr_bus[ix], INPUT);
    pinMode(data_bus[ix], INPUT);
  }

  // Exit progriamming mode the board will
  // take back control of the buses.
  digitalWrite(PRG_PIN, LOW);

  pinMode(WEN_PIN, INPUT);
  pinMode(PRG_PIN, INPUT);
}

void writeProgramByte(byte address, byte data)
{
  pinMode(WEN_PIN, OUTPUT);
  digitalWrite(WEN_PIN, HIGH);

  for (int ix = 0; ix < 8; ix++)
  {
    digitalWrite(addr_bus[ix], (address >> ix) & 1);
  }

  for (int ix = 0; ix < 8; ix++)
  {
    digitalWrite(data_bus[ix], (data >> ix) & 1);
  }
  delay(1);
  digitalWrite(WEN_PIN, LOW);
  delay(15);
  digitalWrite(WEN_PIN, HIGH);

  EEPROM.write(address, data);
}

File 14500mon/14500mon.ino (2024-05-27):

/**********************************************************************
 * Assembler Monitor for PLC14500-Nano board.
 *  Copyright (C) 2023 Nicola Cimmino
 * 
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
 */

#include <EEPROM.h>

#include "src/config.h"
#include "src/hardware.h"
#include "src/monitor.h"
#include "src/bootloader.h"
#include "src/messages.h"

byte data_bus[] = {
    D0_PIN,
    D1_PIN,
    D2_PIN,
    D3_PIN,
    D4_PIN,
    D5_PIN,
    D6_PIN,
    D7_PIN};

byte addr_bus[] = {
    A0_PIN,
    A1_PIN,
    A2_PIN,
    A3_PIN,
    A4_PIN,
    A5_PIN,
    A6_PIN,
    A7_PIN};

byte rxBuffer[RX_BUFFER_SIZE];

uint8_t bootConfig = 0;

void bootloaderSetup()
{
  unsigned long lastResetPress = millis();

  acquireBusForWrite();
  while (true)
  {
    while (analogRead(RST_PIN) < RST_BUTTON_LOW_THRESHOLD)
    {
      digitalWrite(data_bus[0], (millis() % 600) < 200);
      if (millis() - lastResetPress > BOOT_CONFIG_TIMEOUT_MS)
      {
        releaseBus();
        return;
      }
    }

    delay(200);

    if (analogRead(RST_PIN) < RST_BUTTON_LOW_THRESHOLD)
    {
      bootConfig = (bootConfig + 1) % 8;
      Serial.print("BOOT CONFIG ");
      Serial.println(bootConfig);
      lastResetPress = millis();

      for (int ix = 0; ix < 8; ix++)
      {
        digitalWrite(addr_bus[ix], (bootConfig >> ix) & 1);
      }
    }

    digitalWrite(data_bus[0], (millis() % 600) < 200);
  }
}

void setup()
{
  pinMode(WEN_PIN, OUTPUT);
  pinMode(PRG_PIN, OUTPUT);

  Serial.begin(9600);

  pinMode(RST_PIN, INPUT);
  if (analogRead(RST_PIN) > RST_BUTTON_LOW_THRESHOLD)
  {
    bootloaderSetup();
  }

  loadBlockIntoProgramMemory(bootConfig & 0b00000011);
}

void loop()
{
  // Demo mode if anything is set in BIT2
  if (bootConfig & 0b00000100)
  {
    static unsigned long lastProgramChange = 0;
    static uint8_t demoIndex = 0;
    if (millis() - lastProgramChange > DEMO_MODE_CHANGE_INTERVAL)
    {
      // BIT0 and BIT1 are the amount of programs in demo mode.
      demoIndex = (demoIndex + 1) % ((bootConfig & 0b00000011) + 1);
      loadBlockIntoProgramMemory(demoIndex);
      lastProgramChange = millis();
    }

    return;
  }

  byte result = enterBootloader();

  if (result == BOOT_ENTER_MONITOR)
  {
    enterMonitor();
  }

  if (result == BOOT_OK)
  {
    // Persist the program to the arduino EEPROM so we can bootstrap the board on powerup.
    for (int address = 0; address < PROGRAM_MEMOMORY_SIZE; address++)
    {
      EEPROM.write(address, rxBuffer[address]);
    }

    // Here we always enter program 0 because we just came out of a successful upload.
    loadBlockIntoProgramMemory(0);
  }
}

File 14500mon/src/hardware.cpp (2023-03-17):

#include "hardware.h"

/**********************************************************************
 *  Acquire the PLC14500 data and address buses by setting the 
 *  program counter and RAM to High-Z outputs (WEN and PRG pin),
 *  and then setting our lines to output (avoid bus contention).
 */

void acquireBusForWrite()
{
  digitalWrite(WEN_PIN, HIGH);
  digitalWrite(PRG_PIN, HIGH);

  for (int ix = 0; ix < 8; ix++)
  {
    pinMode(addr_bus[ix], OUTPUT);
    pinMode(data_bus[ix], OUTPUT);
  }
}

void acquireBusForRead()
{
  digitalWrite(WEN_PIN, HIGH);
  digitalWrite(PRG_PIN, LOW);

  for (int ix = 0; ix < 8; ix++)
  {
    pinMode(addr_bus[ix], INPUT);
    pinMode(data_bus[ix], INPUT);
  }
}

byte readAddressFromBus()
{
  byte address = 0;

  for (int ix = 0; ix < 8; ix++)
  {
    address = address | (digitalRead(addr_bus[ix]) << ix);
  }

  return address;
}

byte readDataFromBus()
{
  byte data = 0;

  for (int ix = 0; ix < 8; ix++)
  {
    data = data | (digitalRead(data_bus[ix]) << ix);
  }

  return data;
}

/*
 **********************************************************************/

/**********************************************************************
 *  Release the PLC14500 data and address buses by setting the 
 *  program counter and RAM to active outputs (WEN and PRG pin),
 *  after setting our lines to input (avoid bus contention).
 */

void releaseBus()
{
  for (int ix = 0; ix < 8; ix++)
  {
    pinMode(addr_bus[ix], INPUT);
    pinMode(data_bus[ix], INPUT);
  }

  digitalWrite(WEN_PIN, HIGH);
  digitalWrite(PRG_PIN, LOW);
}

/*
 **********************************************************************/

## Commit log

2015-02-01 Added board picture
2015-02-03 Updated board picture
2015-02-03 Updated board image
2015-02-03 Added full resolution board image
2015-02-03 Added monostable schematic
2015-02-04 Added schematic
    [PLC-14500.sch]
2015-02-04 Corrected schematic
2022-11-03 Add board
    [IO.sch, plc14500.kicad_pcb, plc14500.sch]
2022-11-07 Schema updates, add loopback and timer
    [CPU.sch, IO.sch, plc14500.kicad_pcb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]
2022-11-09 Add assembler skeleton
    [IO.sch]
2022-11-09 Add scratchpad ram
    [CPU.sch, IO.sch, SPRAM.sch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]
2022-11-09 Schematic tweaks
    [CPU.sch, IO.sch, SPRAM.sch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]
2022-11-09 First working assembler proto
2022-11-12 All components on the board! WIP
    [IO.sch, SPRAM.sch, plc14500.kicad_pcb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]
2022-11-12 Board preview
2022-11-12 Remove old assembler
2022-11-12 Remove old schema
    [PLC-14500.sch]
2022-11-13 Fix JMP
    [CPU.sch, plc14500.kicad_pcb]
2022-11-16 Board routing
    [CPU.sch, plc14500.dsn, plc14500.kicad_pcb]
2022-11-16 Nano board rev-a prod ready
    [CPU.sch, IO.sch, SPRAM.sch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]
2022-11-16 Few more blocks
    [plc14500-B_Cu.gbr, plc14500-B_Mask.gbr, plc14500-B_Paste.gbr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]
2022-11-17 Add press button as on board
2022-11-18 Update board 3d models
    [CPU.sch, DPDT_Switch.FCStd, IO.sch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]
2022-11-21 Add metadata to assembler
2022-11-22 Add board svgs
    [plc14500-B_Cu.gbr, plc14500-B_Mask.gbr, plc14500-B_Paste.gbr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]
2022-11-22 Add load button to simulator
2022-11-23 Add schematic in PDF format for easier peruse
    [CPU.sch, IO.sch, plc14500.kicad_pcb]
2022-11-25 Fix bootloader, add labels to aseembler
    [CPU.sch, IO.sch, SPRAM.sch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]
2022-11-27 First release artifacts
    [CPU.sch, SPRAM.sch, plc14500.kicad_pcb]
2022-11-28 Add build script, some kit packaging material
2022-11-29 Add oshw cert, add missing drill file
    [plc14500-NPTH.drl, plc14500-PTH.drl]
2022-11-29 Refactor, add board specific code
    [plc14500.kicad_pcb]
2022-11-30 Programmers guide, WIP
    [IO.sch]
2022-12-06 Rev_b board
    [IO.sch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]
2023-01-02 Updates in preparation for rel 1
    [CPU.sch, IO.sch, SPRAM.sch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]
2023-01-03 Small fixes to schema/assembly layout after test assembly
    [CPU.sch, plc14500.kicad_pcb]
2023-01-03 Leaflet, fix couple of typos
2023-01-04 Fix Arduino label to fit ziplock
2023-01-17 Add Arduino installation note
2023-02-06 Update bom and assembly plan for new RAM code
    [PLC14500-Nano-Support-MainPlate.stl, PLC14500-Nano-Support-MainPlateSupports.stl, PLC14500-Nano-Support.FCStd]
2023-02-12 Tweak BOM
2023-02-17 Rescue some missing symbols that were broken
    [CPU.sch, IO.sch, SPRAM.sch]
2023-02-19 Experimental: assemble using cc65
    [plc14500-nano-b.cfg]
2023-02-19 Make mnemonics case-insensitive
2023-03-11 Move assembler extension for CC65 to a separate repo
    [plc14500-nano-b.cfg]
2023-03-17 REV.C (#6)
    REV.C board updates
    [CPU.sch, IO.sch, SPRAM.sch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]
2023-04-01 Nicola/14500mon (#8)
    * Messages cleanup
    * Refactor
    * Refactor
    * Refactor
    * Add load/save, make assembled program runnable immediately
    * Fix few annoying bugs
    * 14500MON Final touches
    * Cleanup readme
    * Add 14500MON screenshot
    * Add credit
    [14500mon.ino, bootloader.cpp, hardware.cpp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]
2023-04-21 Add REV.C board renders
2023-05-10 Fix Assemble command doesn't take HEX arguments. Thanks, Bernard, for noticing.
    [monitor.cpp]
2023-10-26 Convert to kicad7.0
    [CPU.kicad_sch, IO.kicad_sch, SPRAM.kicad_sch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]
2024-01-25 Fix smoketest.asm to match printed leaflets
2024-04-09 More examples for board rev. c (#16)
    * REV.C
    * REV.C
2024-05-26 Ingore board backups
2024-05-27 Add 14500MON bootloader config shortcut
    [14500mon.ino]
2024-08-06 Fix assembler.dart is gitignored
2024-08-07 Update README.md
    Fix reference to CC64 assembler repo
2024-08-20 Feature/rev.d (#19)
    * First tests for a rust upload tool, WIP
    * Rearrange LEDs
    * Remove kicad backups
    * REV.D Schema updates
    * Restore PCB anchoring holes
    * Address ERC errors
    * Cleanup, ready to route
    * REV.D first proto
    * Fix issues on REV.D0
    * REV.D schema fixes, better assembler output, some docs
    * Add ignore of kicad lock files
    * Fixes
    * route
    * Re-route REV.D, fab files next round
    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
    [CPU.kicad_sch, IO.kicad_sch, SPRAM.kicad_sch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]
2024-08-20 Generate new 3d view
    [SK2202.step, plc14500.kicad_pcb]
2024-09-04 Fix/rst line (#20)
    * Clear OUT and SPR on program
    * Fix RST line pulsing on program upload doesn't work
    * Bump bootloader version to 1.3
    [plc14500-B_Cu.gbr, plc14500-B_Mask.gbr, plc14500-B_Paste.gbr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]
2025-07-13 flash-rs fleshed out (#22)
    * rearranged flash-rs to handle keyboard input and serial communication asynchronously
    * Fleshed out flash-rs, so it can successfully upload a program and then fall into the interactive monitor. It can become stuck in the trace routine, but you can get it out by switching to the fast mode or by hitting the reset switch on the Arduino.
    * Added README.md to flash-rs
    ---------
    [main.rs]
2026-04-27 New experimental unified tool (#23)
    Assembler and uploader.
    Works in Linux and Windows with gitBash at least.
    [PLC14500-Nano-SupportV2-MainPlate.stl, PLC14500-Nano-SupportV2.FCStd]

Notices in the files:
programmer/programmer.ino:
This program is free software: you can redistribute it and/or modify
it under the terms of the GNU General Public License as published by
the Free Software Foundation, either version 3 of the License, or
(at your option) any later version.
